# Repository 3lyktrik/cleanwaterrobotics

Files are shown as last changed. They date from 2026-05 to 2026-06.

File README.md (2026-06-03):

# Clean Water Robotics
Είμαστε η ομάδα **"Clean Water Robotics"** από το **3ο ΓΕΛ Τρικάλων "Οδυσσέας Ελύτης"** και στα πλαίσια της συμμετοχής μας στον **"8ο Πανελλήνιο Διαγωνισμό Ανοιχτών Τεχνολογιών στην Εκπαίδευση"** υλοποιήσαμε το έργο **"Αυτόνομο Ρομπότ Συλλογής Μικροπλαστικών από Υδάτινα Οικοσυστήματα"**.

## Το πρόβλημα
Ένα πολύ μεγάλο πρόβλημα της σύγχρονης εποχής είναι το πρόβλημα των μικροπλαστικών.
Τα μικροπλαστικά είναι μικροσκοπικά σωματίδια πλαστικού με μέγεθος μικρότερο από 5 χιλιοστά.

Λόγω του μεγέθους τους, είναι συχνά αόρατα με γυμνό μάτι, αλλά βρίσκονται πλέον παντού: στους ωκεανούς, στο έδαφος, στον αέρα, ακόμα και στον ανθρώπινο οργανισμό.

Επίσης ανιχνεύονται στα ποτάμια και στις λίμνες, καθώς και σε όλες τις υδάτινες διαδρομές από την ξηρά έως τη θάλασσα.

Τα μικροπλαστικά αποτελούν τεράστιο πρόβλημα τόσο για το περιβάλλον, όσο και για όλους τους ζωντανούς οργανισμούς, καθώς δεν βιοδιασπώνται εύκολα, παραμένουν στο περιβάλλον για αιώνες, εισέρχονται στην τροφική αλυσίδα των ζώων και του ανθρώπου, περιέχουν τοξικά πρόσθετα που μπορεί να προκαλέσουν πολλά προβλήματα υγείας, κλπ

Για την αντιμετώπιση του προβλήματος των μικροπλαστικών έχουν προταθεί διάφορες λύσεις.

Δείτε αναλυτικά την **έρευνα** που κάναμε για αυτό το πρόβλημα στο [docs/Έρευνα.md](docs/Έρευνα.md).

## Η λύση: “Αυτόνομο Ρομπότ Συλλογής Μικροπλαστικών από Υδάτινα Οικοσυστήματα”
Η ομάδα μας σχεδίασε και κατασκεύασε ένα αυτόνομο ρομποτικό σκάφος, με στόχο τη μείωση της ρύπανσης από πλαστικά στα υδάτινα οικοσυστήματα, μέσω ελεγχόμενου φιλτραρίσματος του νερού.
Το έργο μας επικεντρώνεται στην πρόληψη της μεταφοράς πλαστικών σωματιδίων από τα εσωτερικά ύδατα (ποτάμια, λίμνες) προς τη θάλασσα, συμβάλλοντας στην προστασία όλων  των υδάτινων οικοσυστημάτων.

Πρόκειται για ένα σκάφος τύπου καταμαράν, που κατασκευάσαμε από σωλήνες PVC διαμέτρου Φ100.

Το σκάφος ελέγχεται από ένα μικροελεγκτή arduino και κινείται με τη βοήθεια δύο ανεξάρτητων κινητήρων, οι οποίοι δίνουν κίνηση σε δύο προπέλες.

Η ενέργεια παρέχεται από μια επαναφορτιζόμενη μπαταρία και πάνω στο σκάφος υπάρχει ηλιακό πάνελ για τη φόρτισή της.

Ο καθαρισμός του νερού από τα μικροπλαστικά γίνεται με φιλτράρισμα, με βυθιζόμενη αντλία σε ελεγχομένο βάθος.

Η πλοήγηση του σκάφους γίνεται με 3 τρόπους:
- με τηλεχειρισμό, μέσω μιας εφαρμογής για κινητά android που αναπτύξαμε
- με κάμερα τεχνητής νοημοσύνης που εντοπίζει μια  πινακίδα στην όχθη και καθοδηγεί ανάλογα το σκάφος
- με χειρονομίες, μέσω κατάλληλης κάμερας αναγνώρισης χειρονομιών

Επίσης γίνεται παρακολούθηση του σκάφους με GPS.

Δείτε αναλυτικά όλες τις λεπτομέρειες της λύσης μας, το σχεδιασμό, την υλοποίηση, τα υλικά και το κόστος εδώ: [docs/Σχεδιασμός.md](docs/Σχεδιασμός.md)

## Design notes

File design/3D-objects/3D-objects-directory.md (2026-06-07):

Στο φάκελο 3D-objects βρίσκονται τα αρχεία stl από το TinkerCAD.
Πρόκειται για τις προπέλες, την τροχαλία και τις βάσεις του servo, των κινητήρων, των πλωτήρων και του φίλτρου.
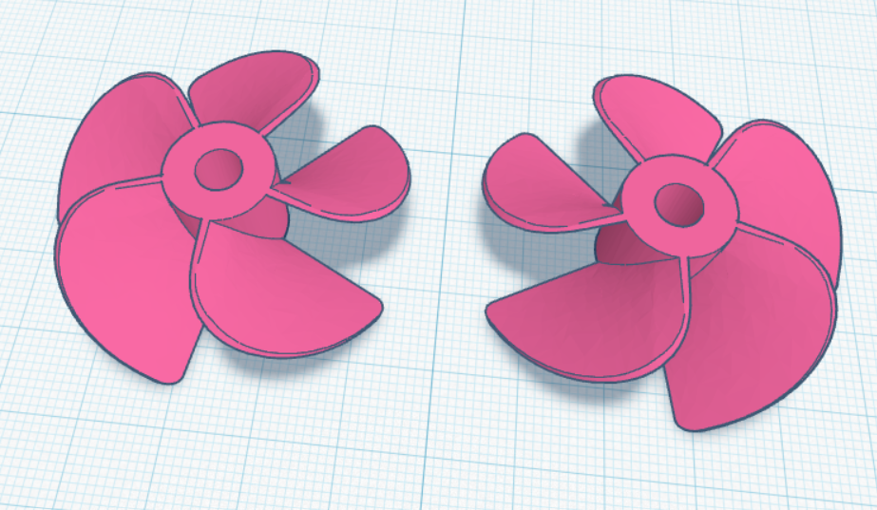
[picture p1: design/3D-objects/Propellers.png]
Προπέλες

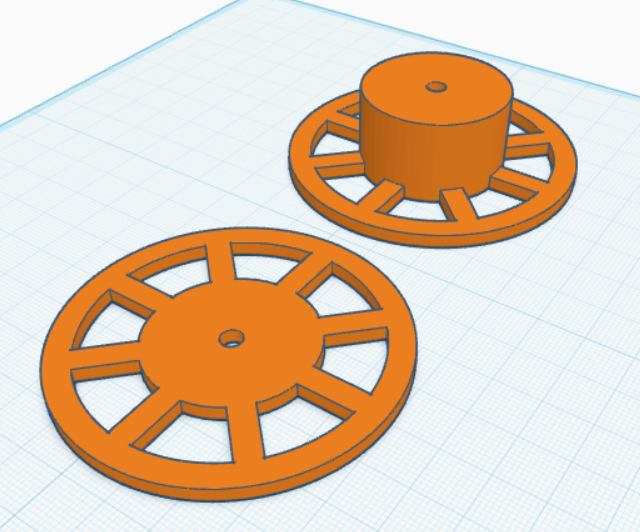
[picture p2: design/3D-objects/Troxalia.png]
Τροχαλία

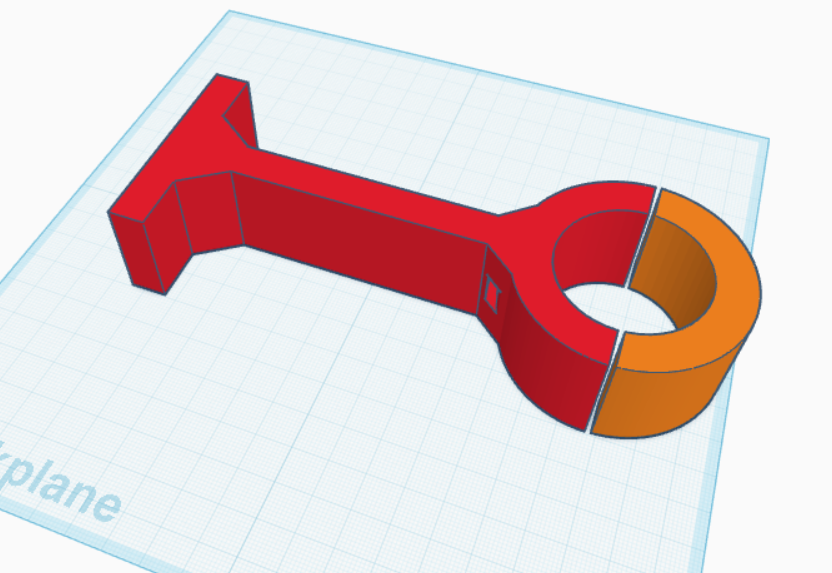
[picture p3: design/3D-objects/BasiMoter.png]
Βάση μοτέρ

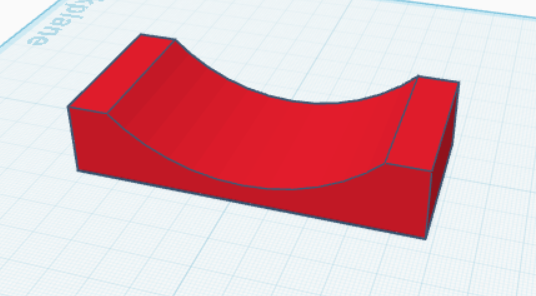
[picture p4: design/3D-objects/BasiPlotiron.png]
Βάση πλωτήρων

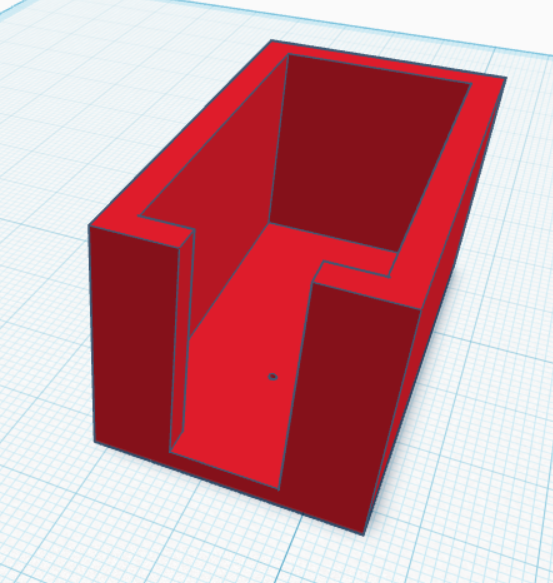
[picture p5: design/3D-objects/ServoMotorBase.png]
Βάση σέρβο

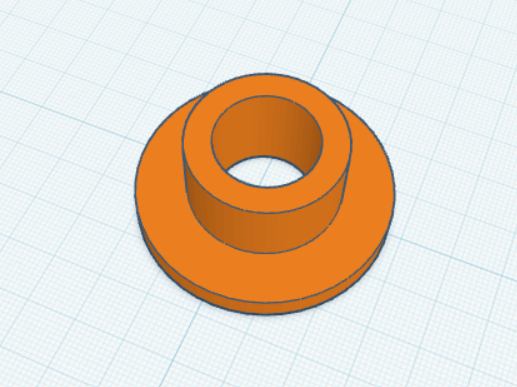
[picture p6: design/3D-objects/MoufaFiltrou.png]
Βάση φίλτρου


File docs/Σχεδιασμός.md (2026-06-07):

# Σχεδιασμός

## Σαφής ορισμός προτεινόμενης λύσης

### Η λύση μας: "Αυτόνομο Ρομπότ Συλλογής Μικροπλαστικών από Υδάτινα Οικοσυστήματα"

Η ομάδα μας σχεδίασε και κατασκεύασε ένα αυτόνομο ρομποτικό σκάφος, με στόχο τη μείωση της ρύπανσης από πλαστικά στα υδάτινα οικοσυστήματα, μέσω ελεγχόμενου φιλτραρίσματος του νερού.

Το έργο μας επικεντρώνεται στην πρόληψη της μεταφοράς πλαστικών σωματιδίων από τα εσωτερικά ύδατα (ποτάμια, λίμνες) προς τη θάλασσα, συμβάλλοντας στην προστασία όλων των υδάτινων οικοσυστημάτων.

Πρόκειται για ένα σκάφος τύπου καταμαράν, που κατασκευάσαμε από σωλήνες PVC διαμέτρου Φ100, για υψηλή πλευστότητα και σταθερότητα. Το σκάφος ελέγχεται από ένα μικροελεγκτή arduino και κινείται με τη βοήθεια δύο ανεξάρτητων κινητήρων, οι οποίοι δίνουν κίνηση σε δύο προπέλες.

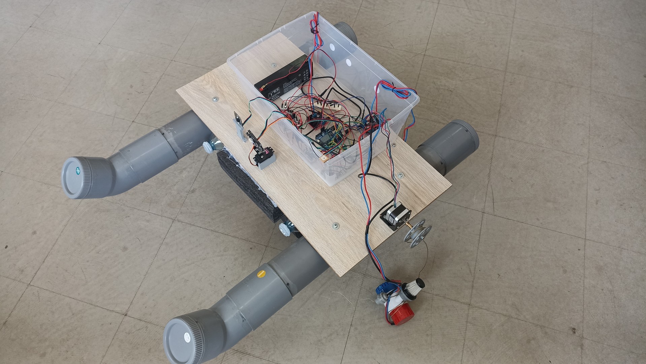
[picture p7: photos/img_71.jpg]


#### Πλοήγηση του σκάφους

Η πλοήγηση του σκάφους γίνεται μέσω της εφαρμογής για κινητά android που αναπτύξαμε με το App Inventor. Η εφαρμογή επικοινωνεί με το σκάφος με Bluetooth Low Energy (BLE). Υλοποιήσαμε 3 τρόπους πλοήγησης:

- **Πλοήγηση με Τηλεχειρισμό**

Στην εφαρμογή υπάρχουν δύο ρυθμιστικά (μπάρες ολίσθησης ή sliders), ένα για την αριστερή προπέλα και ένα για τη δεξιά, που ρυθμίζουν την ταχύτητα των αντίστοιχων κινητήρων. Έχουμε υλοποιήσει 4 ταχύτητες μπροστά και 4 όπισθεν. Οι στροφές του σκάφους επιτυγχάνονται με συνδυασμό ταχυτήτων των δύο κινητήρων (ο ένας μπροστά και ο άλλος όπισθεν).

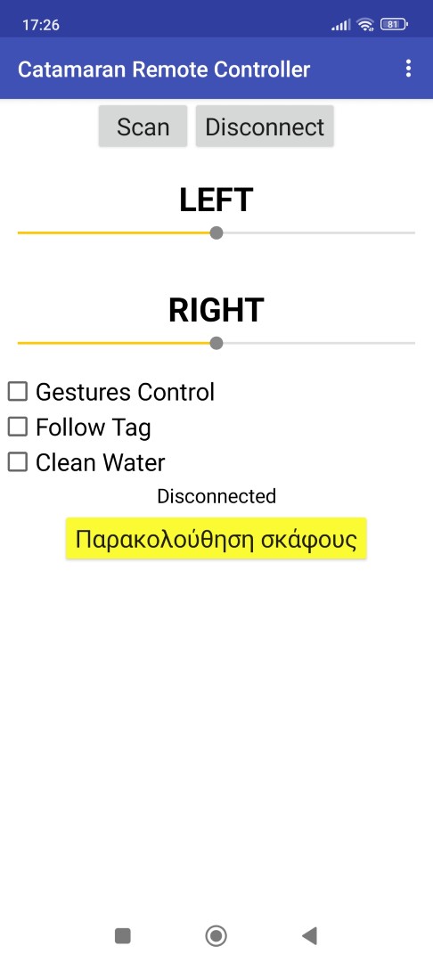
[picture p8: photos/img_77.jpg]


- **Πλοήγηση με χειρονομίες**

Στο σκάφος τοποθετήσαμε μια κάμερα αναγνώρισης χειρονομιών, την οποία χρησιμοποιούμε για να οδηγήσουμε το σκάφος από την όχθη με χειρονομίες. Υλοποιήσαμε τρεις χειρονομίες:

"ΟΚ" (👍) για κίνηση μπροστά, "STOP" (🤚) για σταμάτημα και "τηλέφωνο"(🤙) για κίνηση προς τα πίσω.

- **Πλοήγηση με κάμερα παρακολούθησης πινακίδας**

Το σκάφος είναι εξοπλισμένο και με μια ακόμα κάμερα τεχνητής νοημοσύνης, που χρησιμοποιούμε για αναγνώριση πινακίδων. Έχουμε εκτυπώσει σε μεγάλο μέγεθος μια πινακίδα με μία συγκεκριμένη εικόνα, η οποία είναι μία από τα λεγόμενα April Tags, που είναι εύκολο να αναγνωριστούν από την κάμερα.

Η κάμερα είναι στερεωμένη πάνω σε έναν κινητήρα servo για να μπορεί να περιστρέφεται. Με την κατάλληλη εντολή από την εφαρμογή του χειριστηρίου ("Follow Tag"), η κάμερα σαρώνει το χώρο για να εντοπίσει την πινακίδα. Αν δεν τη βρει στο οπτικό της πεδίο, τότε δίνει εντολή στο σκάφος να περιστραφεί λίγο, για να σαρώσει τελικά όλο τον κύκλο (360 μοίρες). Μόλις εντοπίσει την πινακίδα, στρίβει το σκάφος κατάλληλα ώστε να την κεντράρει και να αρχίσει να κατευθύνεται προς αυτήν.

Η πινακίδα τοποθετείται στην όχθη για να υποδεικνύει το σημείο επιστροφής του σκάφους, δηλαδή τη "βάση" του.

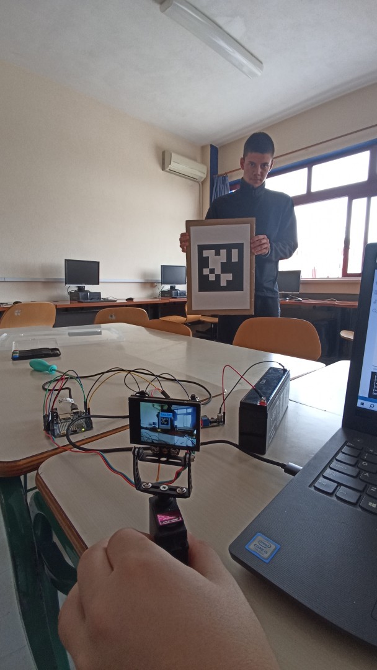
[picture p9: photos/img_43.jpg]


#### Παρακολούθηση του σκάφους με GPS

Για να αποφύγουμε το ενδεχόμενο να παρασυρθεί το σκάφος από τη ροή του ποταμού, χρησιμοποιούμε ένα δέκτη GPS, που καταγράφει τα δεδομένα θέσης του σκάφους (δηλ. συντεταγμένες, κατεύθυνση, ταχύτητα και αριθμός ορατών δορυφόρων) και τα στέλνει στην πλατφόρμα Thingspeak στο διαδίκτυο. Η εφαρμογή του κινητού ανακτά τα δεδομένα αυτά από την πλατφόρμα και απεικονίζει τη θέση του σκάφους πάνω στο χάρτη.

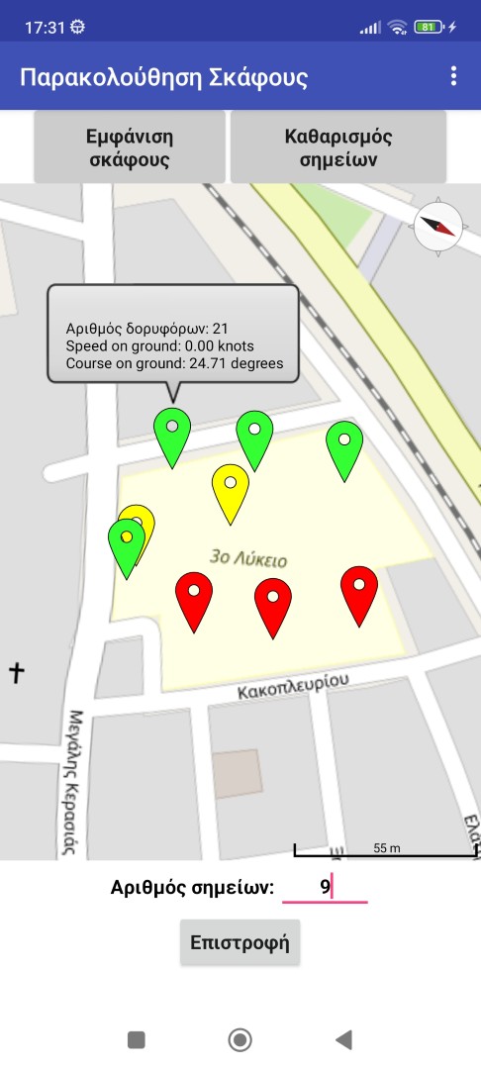
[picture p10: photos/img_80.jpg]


#### Καθαρισμός του νερού

Ο καθαρισμός του νερού από τα πλαστικά και μικροπλαστικά γίνεται με φιλτράρισμα. Το σύστημα καθαρισμού αποτελείται από:

- υποβρύχια αντλία άντλησης νερού
- φίλτρο ειδικά προσαρμοσμένο στην αντλία
- περιστρεφόμενο μηχανισμό καθόδου/ανόδου της αντλίας
- βηματικό κινητήρα για ακριβή έλεγχο της θέσης της αντλίας
- υποβρύχιο αισθητήρα απόστασης για μέτρηση του βάθους

Το φίλτρο είναι προσαρμοσμένο πάνω στην υποβρύχια αντλία. Η υποβρύχια αντλία μπορεί να βυθίζεται μέσα στο νερό, καθώς είναι στερεωμένη σε περιστρεφόμενο τροχό (τροχαλία). Ο τροχός περιστρέφεται με τη βοήθεια ενός βηματικού κινητήρα (stepper motor). Το βάθος που φτάνει η αντλία ελέγχεται με έναν υποβρύχιο αισθητήρα απόστασης. Η εντολή εκκίνησης και τερματισμού του καθαρισμού δίνεται από το χειριστήριο.

Με αυτόν τον τρόπο, το σκάφος μπορεί να πραγματοποιεί στοχευμένο φιλτράρισμα σε διαφορετικά βάθη νερού.

Η ικανότητα καθαρισμού της συγκεκριμένης αντλίας που χρησιμοποιήσαμε φτάνει τα 22 λίτρα/λεπτό και το μέγιστο βάθος λειτουργίας είναι 3.8 μέτρα.

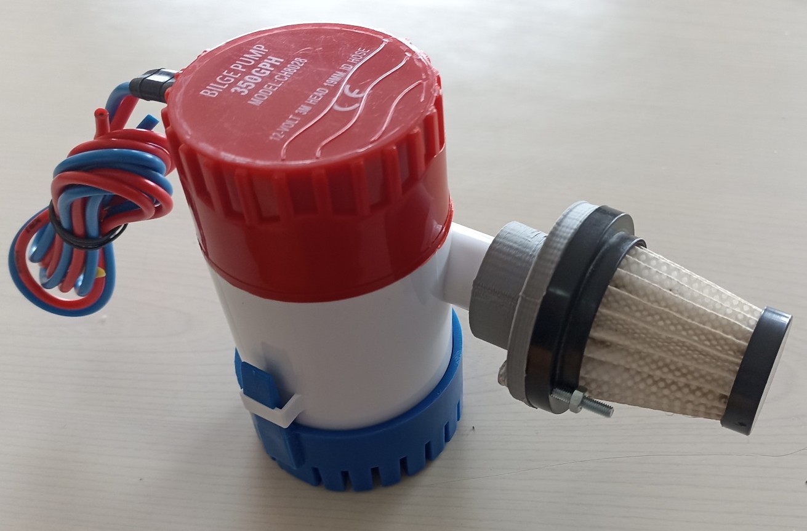
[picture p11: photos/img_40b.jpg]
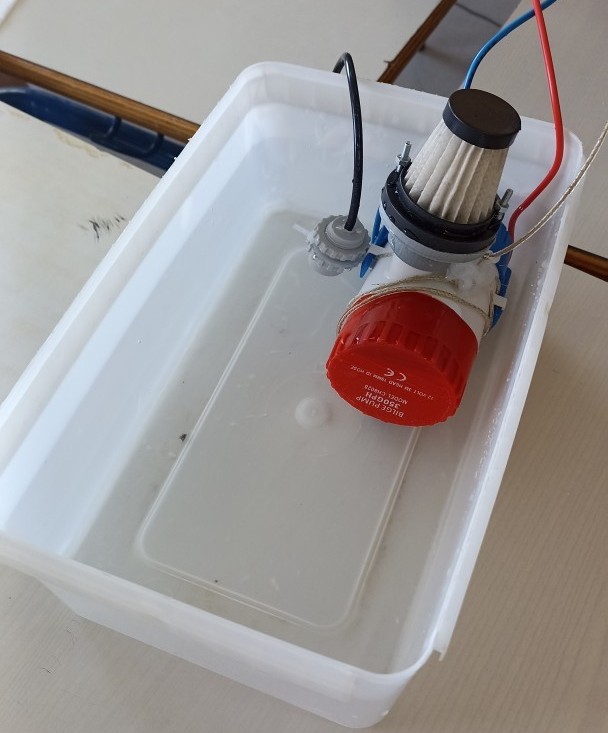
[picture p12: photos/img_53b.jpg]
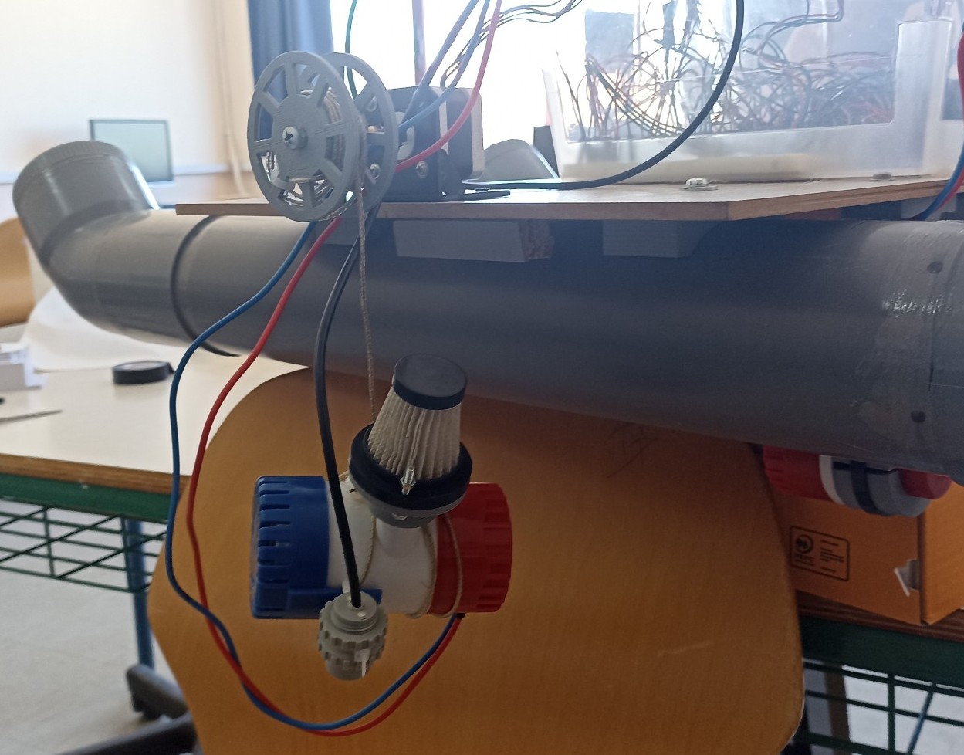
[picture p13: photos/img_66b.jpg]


#### Εκτυπώσεις 3D

Η ομάδα σχεδίασε στο TinkerCAD και εκτύπωσε στον τρισδιάστατο εκτυπωτή του σχολείου τα ακόλουθα αντικείμενα:

- Προπέλες (δεξιόστροφη - αριστερόστροφη)
- Τροχαλία για τη βύθιση της αντλίας καθαρισμού
- Βάσεις στήριξης των κινητήρων του σκάφους
- Βάσεις στήριξης των πλωτήρων (σωλήνων PVC) στο κατάστρωμα
- Βάση μοτέρ servo για την περιστροφή της κάμερας
- Βάση της κάμερας χειρονομιών
- Μούφα για σύνδεση του φίλτρου στην αντλία

Δείτε τα σχέδια παρακάτω.

#### Αυτονομία σκάφους

Το σκάφος λειτουργεί με μία επαναφορτιζόμενη μπαταρία 12V. Για τη φόρτισή της με ενεργειακά αποδοτικό τρόπο, αξιοποιούμε ανανεώσιμες πηγές ενέργειας, καθώς έχουμε εγκαταστήσει στο σκάφος ένα φωτοβολταϊκό πάνελ και μία πλακέτα φόρτισης.

Αρχικά χρησιμοποιήσαμε μικρή μπαταρία 2.3Ah, η οποία αποδείχθηκε ανεπαρκής για τις ανάγκες τροφοδοσίας όλων των κινητήρων ταυτόχρονα, οπότε η χρήση μιας μπαταρίας 9Ah κρίνεται αναγκαία.

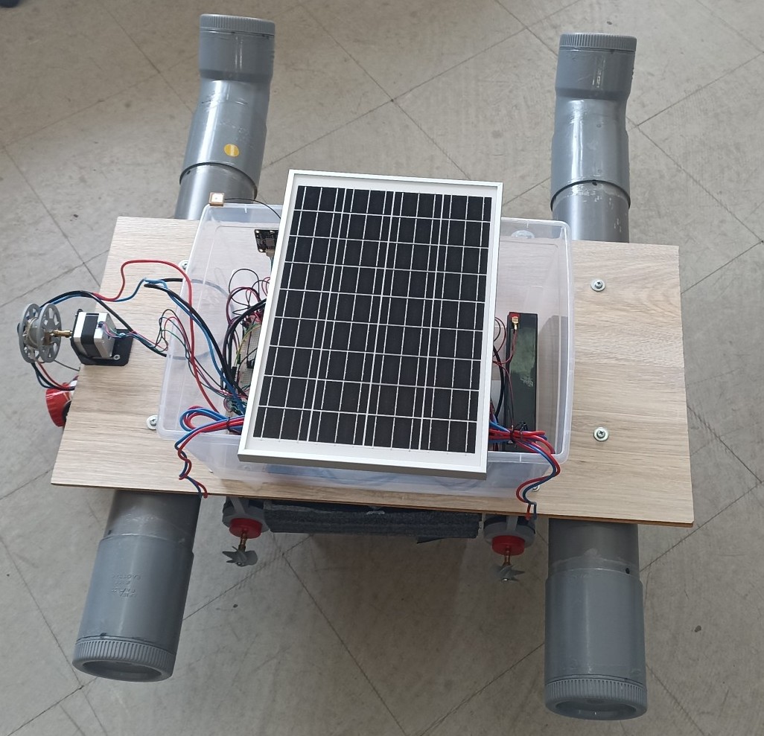
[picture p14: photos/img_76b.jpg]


## Πρωτοτυπία λύσης - καινοτομία

Η καινοτομία του έργου βρίσκεται:

- στον συνδυασμό πλωτού σκάφους και φιλτραρίσματος
- στον δυναμικό έλεγχο του βάθους καθαρισμού
- στην ποικιλία τρόπων πλοήγησης
- στη δυνατότητα αυτόνομης λειτουργίας
- στη χρήση ανοιχτών τεχνολογιών χαμηλού κόστους
- στη δυνατότητα εύκολης ανακατασκευής του έργου

## Λίστα υλικών και εργαλείων - Κόστος

|**Α/Α**|  **Είδος** |  **Περιγραφή** | **Τιμή** | **Τεμάχια** |  **Σύνολο**|
|----|---|---|---|---|---|
| 1 | Arduino | Arduino UNO R4 WiFi | 32,80 | 1 | 32,80 |
| 2 | Κουτί αδιάβροχο | Sonoff IP66 Waterproof Case | 4,90 | 1 | 4,90 |
| 3 | Πλακέτα δοκιμών | Πλακέτα Δοκιμών 400 Οπές - Άσπρη | 2,20 | 1 | 2,20 |
| 4 | Καλώδια | Jumper Wires 15cm Male to Male - Pack of 10 | 1,80 | 3 | 5,40 |
| 5 | Καλώδια | Jumper Wires 15cm Female to Male - Pack of 10 | 1,80 | 2 | 3,60 |
| 6 | Οδηγός κινητήρων DC | Dual Motor Driver Module L298N | 4,20 | 2 | 8,40 |
| 7 | Οδηγός κινητήρων stepper | DRV8825 Stepper Motor Driver | 3,20 | 1 | 3,20 |
| 8 | Βηματικός κινητήρας | Βηματικός Κινητήρας 2.8kg.cm (200 steps/rev) 42BYGHW208 | 12,60 | 1 | 12,60 |
| 9 | Αντλία και κινητήρες | Bilge Water Pump 12V 350GPH | 16,80 | 3 | 50,40 |
| 10 | Κινητήρας Servo | Waveshare MG996R Standard Servo with Metal Gears - 11kg·cm | 8,90 | 1 | 8,90 |
| 11 | Υποβρύχιος αισθητήρας απόστασης | Underwater Ultrasonic Distance Sensor IP68 - UART, 3m Range | 39,90 | 1 | 39,90 |
| 12 | Κάμερα AI | Gravity HUSKYLENS - An Easy-to-use AI Machine Vision Sensor | 69,90 | 1 | 69,90 |
| 13 | Κάμερα AI για χειρονομίες | DFRobot Gravity Gesture & Face Detection AI Sensor | 19,90 | 1 | 19,90 |
| 14 | Δέκτης GPS | Gravity GNSS GPS BeiDou Receiver Module - I2C&UART | 22,80 | 1 | 22,80 |
| 15 | Μπαταρία | Μπαταρία Μολύβδου 12V 2.3Ah | 9,60 | 1 | 9,60 |
| 16 | Φορτιστής για φωτοβολταϊκό | DFRobot Solar Power Manager for 12V Lead-Acid Battery | 35,90 | 1 | 35,90 |
| 17 | Φωτοβολταϊκό | Waveshare Φωτοβολταϊκή Κυψέλη 10W 340x232mm | 14,80 | 1 | 14,80 |
| 23 | Νήμα 3D εκτύπωσης | Creality Ender-PLA - 1.75mm 1kg Black | 14 | 1 | 14,00 |
| 24 | Σταθεροποιητής τάσης 5V | Voltage Regulator L7805CV - 5V 1.5A | 0,40 | 1 | 0,40 |
| 25 | Ψύκτρα | Ψύκτρα ΤO-220 20x15x10mm | 0,30 | 1 | 0,30 |
| 26 | Καλώδιο USB | Καλώδιο USB A Αρσενικό σε C Αρσενικό - 1m Μαύρο 3A | 2,30 | 1 | 2,30 |
| 27 | Σύνδεσμοι αξόνων | Shaft Coupler Solid 3.175mm - 5mm | 1,80 | 3 | 5,40 |
| 28 | Μετατροπέας τάσης | Lm2596s Dc-dc Step-down Power Supply | 2,47 | 1 | 2,47 |
| 29 | Σωλήνες PVC Φ100, γωνίες, μούφες, τάπες | | 40,00 | 1 | 40,00 |
| | | | | | |
| | | | **ΣΥΝΟΛΟ:** | | 410,07 |

## Σχέδια

Το αναλυτικό κύκλωμα φαίνεται στην παρακάτω εικόνα:
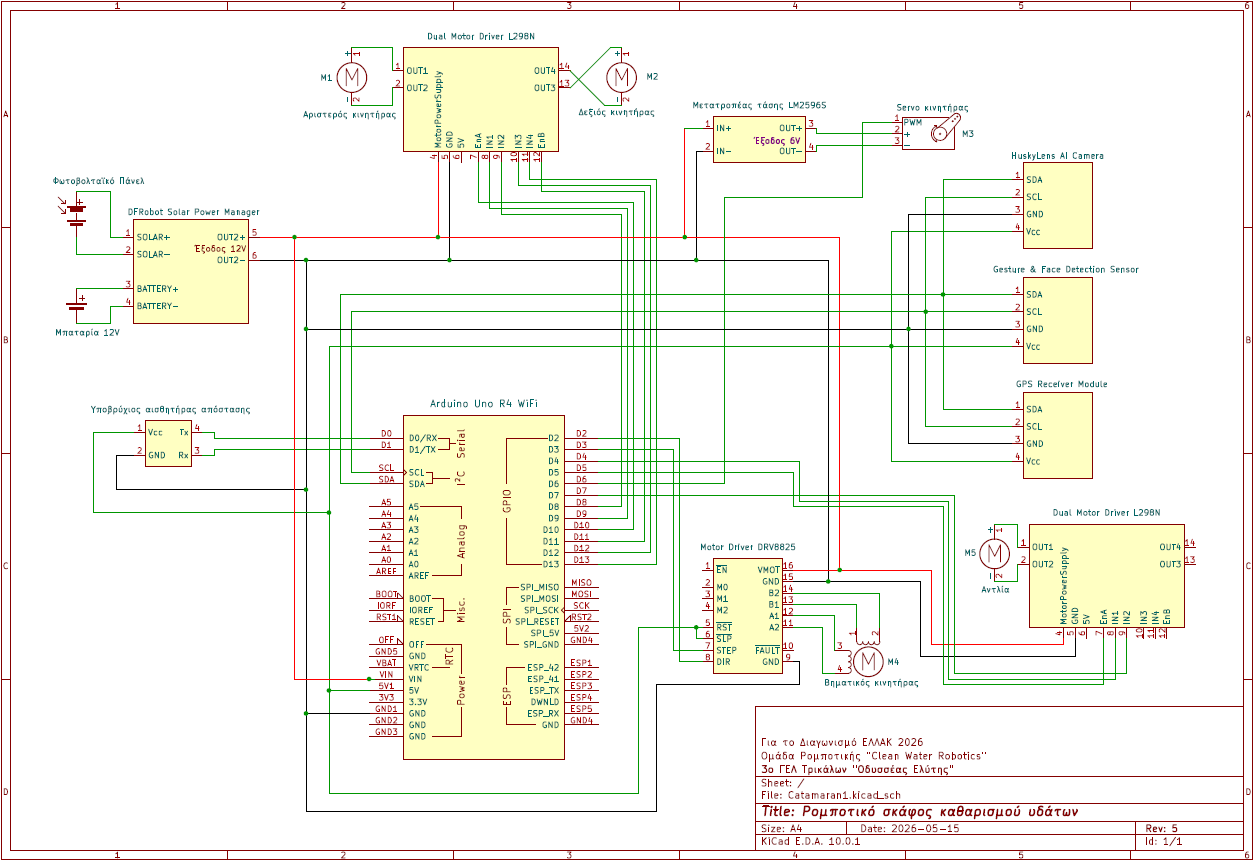
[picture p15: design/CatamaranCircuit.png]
Κύκλωμα


### Προπέλες
Προπέλες

### Τροχαλία
Τροχαλία

### Βάση servo
Βάση servo

### Βάση κινητήρων
Βάση μοτέρ

### Βάση πλωτήρων
Βάση πλωτήρων

### Βάση φίλτρου
Βάση φίλτρου

Βρείτε όλα τα αρχεία stl [εδώ](/design/3D-objects).

## Βασικός αλγόριθμος Arduino - App Inventor
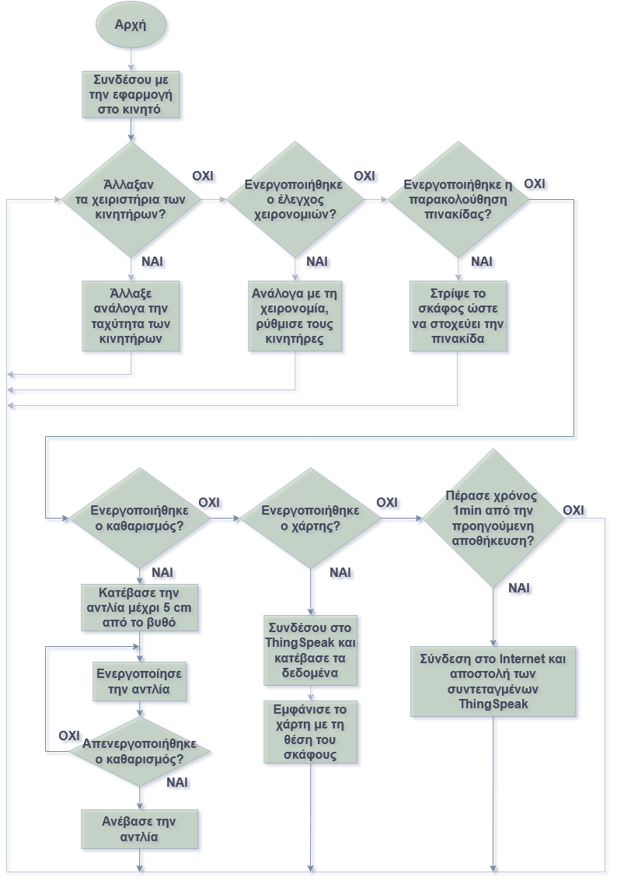
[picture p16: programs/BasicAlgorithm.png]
Βασικός Αλγόριθμος


## Αφίσα
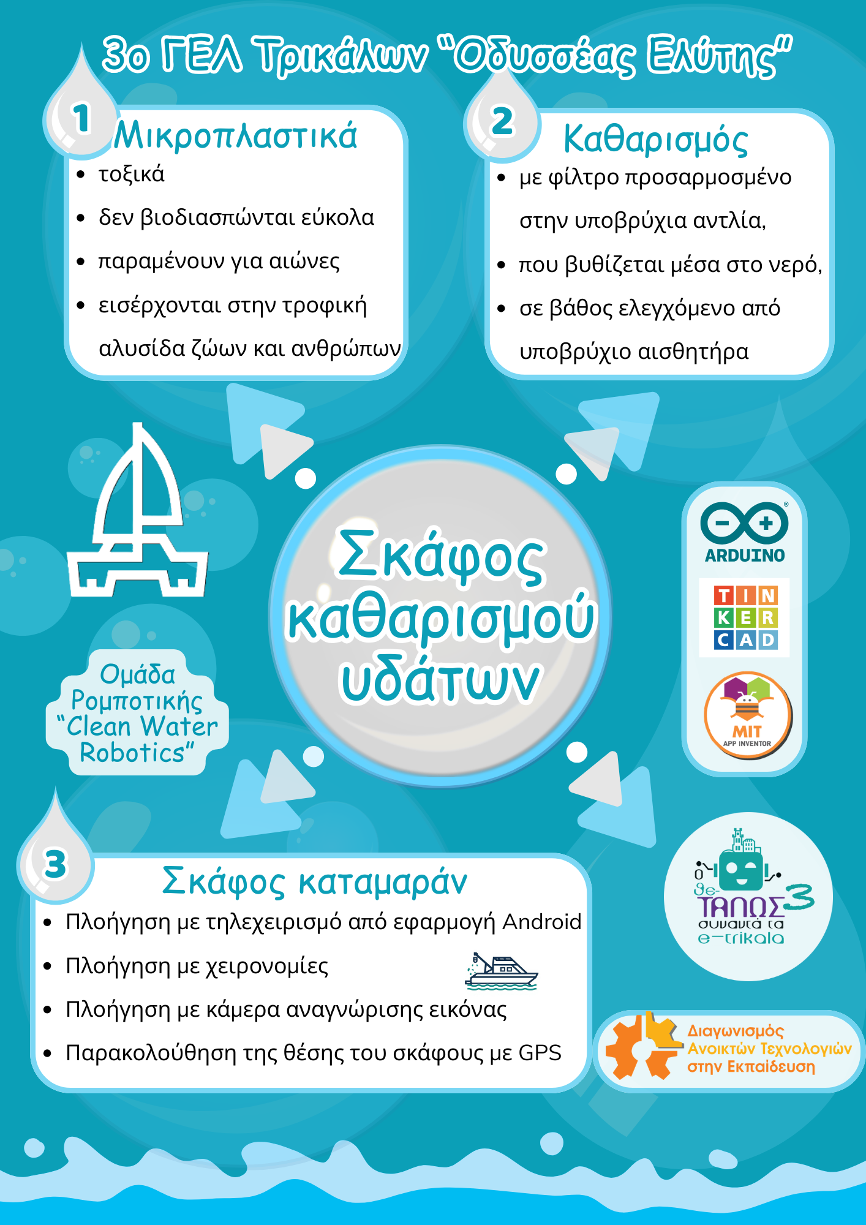
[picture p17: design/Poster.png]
Αφίσα


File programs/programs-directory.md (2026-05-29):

Εδώ βρίσκονται τα προγράμματα για το Arduino.

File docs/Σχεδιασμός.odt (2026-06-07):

# Σχεδιασμός

## Σαφής ορισμός προτεινόμενης λύσης

### Η λύση μας: “Αυτόνομο Ρομπότ Συλλογής Μικροπλαστικών από Υδάτινα Οικοσυστήματα”

Η ομάδα μας σχεδίασε και κατασκεύασε ένα αυτόνομο ρομποτικό σκάφος, με στόχο τη μείωση της ρύπανσης από πλαστικά στα υδάτινα οικοσυστήματα, μέσω ελεγχόμενου φιλτραρίσματος του νερού.

Το έργο μας επικεντρώνεται στην πρόληψη της μεταφοράς πλαστικών σωματιδίων από τα εσωτερικά ύδατα (ποτάμια, λίμνες) προς τη θάλασσα, συμβάλλοντας στην προστασία όλων των υδάτινων οικοσυστημάτων.

Πρόκειται για ένα σκάφος τύπου καταμαράν, που κατασκευάσαμε από σωλήνες PVC διαμέτρου Φ100, για υψηλή πλευστότητα και σταθερότητα. Το σκάφος ελέγχεται από ένα μικροελεγκτή arduino και κινείται με τη βοήθεια δύο ανεξάρτητων κινητήρων, οι οποίοι δίνουν κίνηση σε δύο προπέλες.

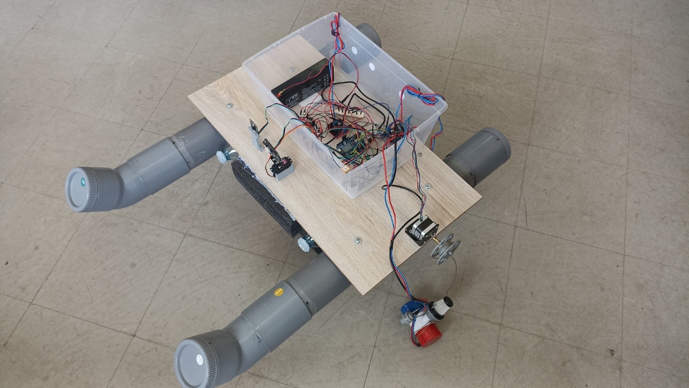
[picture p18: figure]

#### Πλοήγηση του σκάφους

Η πλοήγηση του σκάφους γίνεται μέσω της εφαρμογής για κινητά android που αναπτύξαμε με το App Inventor. Η εφαρμογή επικοινωνεί με το σκάφος με Bluetooth Low Energy (BLE). Υλοποιήσαμε 3 τρόπους πλοήγησης:

1. Πλοήγηση με Τηλεχειρισμό

Στην εφαρμογή υπάρχουν δύο ρυθμιστικά (μπάρες ολίσθησης ή sliders), ένα για την αριστερή προπέλα και ένα για τη δεξιά, που ρυθμίζουν την ταχύτητα των αντίστοιχων κινητήρων. Έχουμε υλοποιήσει 4 ταχύτητες μπροστά και 4 όπισθεν. Οι στροφές του σκάφους επιτυγχάνονται με συνδυασμό ταχυτήτων των δύο κινητήρων (ο ένας μπροστά και ο άλλος όπισθεν).

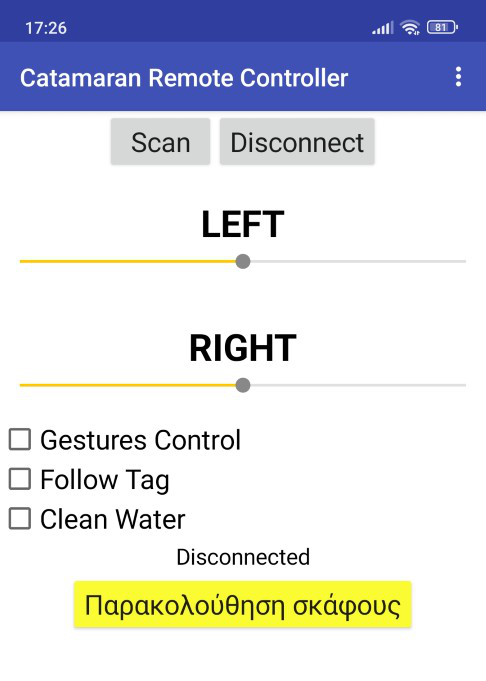
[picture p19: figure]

2. Πλοήγηση με χειρονομίες

Στο σκάφος τοποθετήσαμε μια κάμερα αναγνώρισης χειρονομιών, την οποία χρησιμοποιούμε για να οδηγήσουμε το σκάφος από την όχθη με χειρονομίες. Υλοποιήσαμε τρεις χειρονομίες:

“ΟΚ” (👍) για κίνηση μπροστά, “STOP” (🤚) για σταμάτημα και “τηλέφωνο”(🤙) για κίνηση προς τα πίσω.

3. Πλοήγηση με κάμερα παρακολούθησης πινακίδας

Το σκάφος είναι εξοπλισμένο και με μια ακόμα κάμερα τεχνητής νοημοσύνης, που χρησιμοποιούμε για αναγνώριση πινακίδων. Έχουμε εκτυπώσει σε μεγάλο μέγεθος μια πινακίδα με μία συγκεκριμένη εικόνα, η οποία είναι μία από τα λεγόμενα April Tags, που είναι εύκολο να αναγνωριστούν από την κάμερα.

Η κάμερα είναι στερεωμένη πάνω σε έναν κινητήρα servo για να μπορεί να περιστρέφεται. Με την κατάλληλη εντολή από την εφαρμογή του χειριστηρίου (“Follow Tag”), η κάμερα σαρώνει το χώρο για να εντοπίσει την πινακίδα. Αν δεν τη βρει στο οπτικό της πεδίο, τότε δίνει εντολή στο σκάφος να περιστραφεί λίγο, για να σαρώσει τελικά όλο τον κύκλο (360 μοίρες). Μόλις εντοπίσει την πινακίδα, στρίβει το σκάφος κατάλληλα ώστε να την κεντράρει και να αρχίσει να κατευθύνεται προς αυτήν.

Η πινακίδα χρησιμοποιείται για να υποδεικνύει το σημείο επιστροφής του σκάφους, δηλαδή τη “βάση” του.


#### Παρακολούθηση του σκάφους με GPS

Για να αποφύγουμε το ενδεχόμενο να παρασυρθεί το σκάφος από τη ροή του ποταμού, χρησιμοποιούμε ένα δέκτη GPS, που καταγράφει τα δεδομένα θέσης του σκάφους (δηλ. συντεταγμένες, κατεύθυνση, ταχύτητα και αριθμός ορατών δορυφόρων) και τα στέλνει στην πλατφόρμα Thingspeak στο διαδίκτυο. Η εφαρμογή του κινητού ανακτά τα δεδομένα αυτά από την πλατφόρμα και απεικονίζει τη θέση του σκάφους πάνω στο χάρτη.

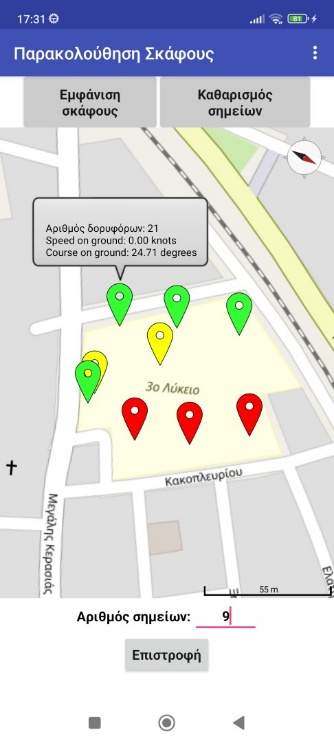
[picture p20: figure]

#### Καθαρισμός του νερού

Ο καθαρισμός του νερού από τα πλαστικά και μικροπλαστικά γίνεται με φιλτράρισμα. Το σύστημα καθαρισμού αποτελείται από:

- υποβρύχια αντλία άντλησης νερού
- φίλτρο ειδικά προσαρμοσμένο στην αντλία
- περιστρεφόμενο μηχανισμό καθόδου/ανόδου της αντλίας
- βηματικό κινητήρα για ακριβή έλεγχο της θέσης της αντλίας
- υποβρύχιο αισθητήρα απόστασης για μέτρηση του βάθους

Το φίλτρο είναι προσαρμοσμένο πάνω στην υποβρύχια αντλία. Η υποβρύχια αντλία μπορεί να βυθίζεται μέσα στο νερό, καθώς είναι στερεωμένη σε περιστρεφόμενο τροχό (τροχαλία). Ο τροχός περιστρέφεται με τη βοήθεια ενός βηματικού κινητήρα (stepper motor). Το βάθος που φτάνει η αντλία ελέγχεται με έναν υποβρύχιο αισθητήρα απόστασης. Η εντολή εκκίνησης και τερματισμού του καθαρισμού δίνεται από το χειριστήριο.

Με αυτόν τον τρόπο, το σκάφος μπορεί να πραγματοποιεί στοχευμένο φιλτράρισμα σε διαφορετικά βάθη νερού.

Η ικανότητα καθαρισμού της συγκεκριμένης αντλίας που χρησιμοποιήσαμε φτάνει τα 22 λίτρα/λεπτό και το μέγιστο βάθος λειτουργίας είναι 3.8 μέτρα.

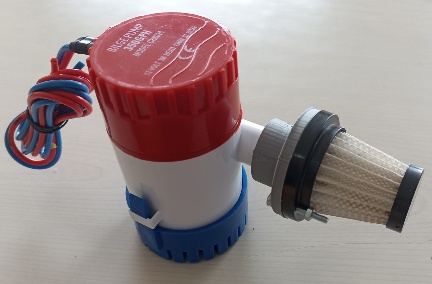
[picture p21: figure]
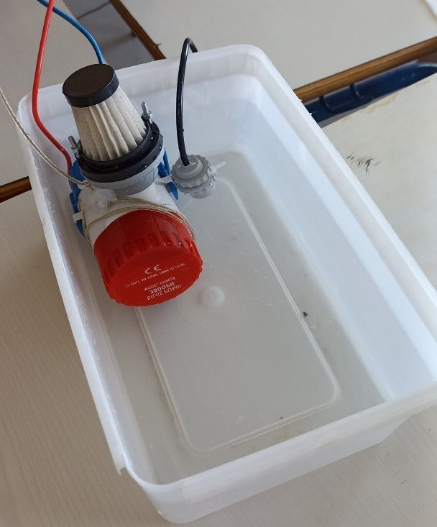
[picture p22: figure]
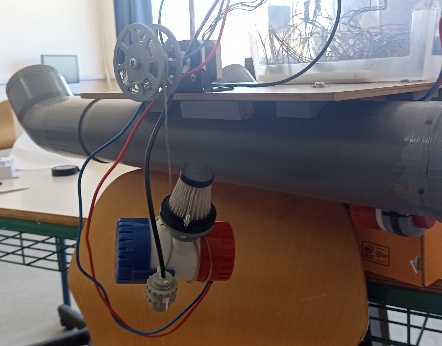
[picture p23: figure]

#### Εκτυπώσεις 3D

Η ομάδα σχεδίασε στο TinkerCAD και εκτύπωσε στον τρισδιάστατο εκτυπωτή του σχολείου τα ακόλουθα αντικείμενα:

- Προπέλες (δεξιόστροφη - αριστερόστροφη)
- Τροχαλία για τη βύθιση της αντλίας καθαρισμού
- Βάσεις στήριξης των κινητήρων του σκάφους
- Βάσεις στήριξης των πλωτήρων (σωλήνων PVC) στο κατάστρωμα
- Βάση μοτέρ servo για την περιστροφή της κάμερας
- Βάση της κάμερας χειρονομιών
- Μούφα για σύνδεση του φίλτρου στην αντλία

Δείτε τα σχέδια παρακάτω.

#### Αυτονομία σκάφους

Το σκάφος λειτουργεί με μία επαναφορτιζόμενη μπαταρία 12V. Για τη φόρτισή της με ενεργειακά αποδοτικό τρόπο, αξιοποιούμε ανανεώσιμες πηγές ενέργειας, καθώς έχουμε εγκαταστήσει στο σκάφος ένα φωτοβολταϊκό πάνελ και μία πλακέτα φόρτισης.

Αρχικά χρησιμοποιήσαμε μικρή μπαταρία 2.3Ah, η οποία αποδείχθηκε ανεπαρκής για τις ανάγκες τροφοδοσίας όλων των κινητήρων ταυτόχρονα, οπότε η χρήση μιας μπαταρίας 9Ah κρίνεται αναγκαία.


## Πρωτοτυπία λύσης - καινοτομία

Η καινοτομία του έργου βρίσκεται:

- στον συνδυασμό πλωτού σκάφους και φιλτραρίσματος
- στον δυναμικό έλεγχο του βάθους καθαρισμού
- στην ποικιλία τρόπων πλοήγησης
- στη δυνατότητα αυτόνομης λειτουργίας
- στη χρήση ανοιχτών τεχνολογιών χαμηλού κόστους
- στη δυνατότητα εύκολης ανακατασκευής του έργου

## Λίστα υλικών και εργαλείων - Κόστος

ΛΙΣΤΑ ΥΛΙΚΩΝ
Α/Α | Είδος | Περιγραφή | Τιμή μονάδας | Τεμάχια | Σύνολο
1 | Arduino | Arduino UNO R4 WiFi | 32,80 | 1 | 32,80
2 | Κουτί αδιάβροχο | Sonoff IP66 Waterproof Case | 4,90 | 1 | 4,90
3 | Πλακέτα δοκιμών | Πλακέτα Δοκιμών 400 Οπές - Άσπρη | 2,20 | 1 | 2,20
4 | Καλώδια | Jumper Wires 15cm Male to Male - Pack of 10 | 1,80 | 3 | 5,40
5 | Καλώδια | Jumper Wires 15cm Female to Male - Pack of 10 | 1,80 | 2 | 3,60
6 | Οδηγός κινητήρων DC | Dual Motor Driver Module L298N | 4,20 | 2 | 8,40
7 | Οδηγός κινητήρων stepper | DRV8825 Stepper Motor Driver | 3,20 | 1 | 3,20
8 | Βηματικός κινητήρας | Βηματικός Κινητήρας 2.8kg.cm (200 steps/rev) 42BYGHW208 | 12,60 | 1 | 12,60
9 | Αντλία και κινητήρες | Bilge Water Pump 12V 350GPH | 16,80 | 3 | 50,40
10 | Κινητήρας Servo | Waveshare MG996R Standard Servo with Metal Gears – 11kg·cm | 8,90 | 1 | 8,90
11 | Υποβρύχιος αισθητήρας απόστασης | Underwater Ultrasonic Distance Sensor IP68 - UART, 3m Range | 39,90 | 1 | 39,90
12 | Κάμερα AI | Gravity HUSKYLENS - An Easy-to-use AI Machine Vision Sensor | 69,90 | 1 | 69,90
13 | Κάμερα AI για χειρονομίες | DFRobot Gravity Gesture & Face Detection AI Sensor | 19,90 | 1 | 19,90
14 | Δέκτης GPS | Gravity GNSS GPS BeiDou Receiver Module - I2C&UART | 22,80 | 1 | 22,80
15 | Μπαταρία | Μπαταρία Μολύβδου 12V 2.3Ah | 9,60 | 1 | 9,60
16 | Φορτιστής για φωτοβολταϊκό | DFRobot Solar Power Manager for 12V Lead-Acid Battery | 35,90 | 1 | 35,90
17 | Φωτοβολταϊκό | Waveshare Φωτοβολταϊκή Κυψέλη 10W 340x232mm | 14,80 | 1 | 14,80
23 | Νήμα 3D εκτύπωσης | Creality Ender-PLA – 1.75mm 1kg Black | 14 | 1 | 14,00
24 | Σταθεροποιητής τάσης 5V | Voltage Regulator L7805CV - 5V 1.5A | 0,40 | 1 | 0,40
25 | Ψύκτρα | Ψύκτρα ΤO-220 20x15x10mm | 0,30 | 1 | 0,30
26 | Καλώδιο USB | Καλώδιο USB A Αρσενικό σε C Αρσενικό - 1m Μαύρο 3A | 2,30 | 1 | 2,30
27 | Σύνδεσμοι αξόνων | Shaft Coupler Solid 3.175mm - 5mm | 1,80 | 3 | 5,40
28 | Μετατροπέας τάσης | Lm2596s Dc-dc Step-down Power Supply | 2,47 | 1 | 2,47
29 | Σωλήνες PVC Φ100, γωνίες, μούφες, τάπες | | 40,00 | 1 | 40,00
| | | ΣΥΝΟΛΟ: | | 410,07

## Σχέδια

Το αναλυτικό κύκλωμα φαίνεται στην παρακάτω εικόνα:

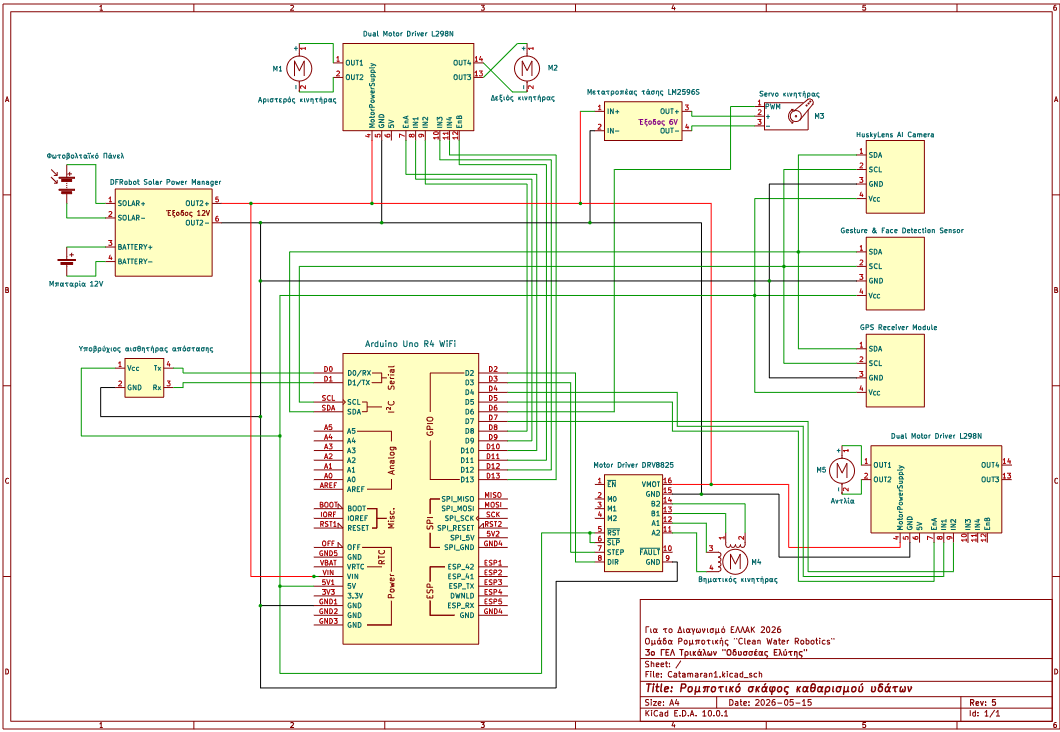
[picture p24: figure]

### Προπέλες


### Τροχαλία


### Βάσεις servo, κινητήρων, πλωτήρων, φίλτρου


## Βασικός αλγόριθμος Arduino - App Inventor


## Αφίσα


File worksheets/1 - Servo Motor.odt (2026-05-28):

Φύλλο Εργασίας 1

Κινητήρας Servo

## Δραστηριότητα 1

Μπείτε στο https://docs.arduino.cc/learn/electronics/servo-motors/ και κάντε τα παραδείγματα Knob και Sweep.

## Δραστηριότητα 2

Προγραμματίστε τον κινητήρα Servo έτσι ώστε να περιστρέφεται σε γωνία 90 μοιρών.

## Δραστηριότητα 3

Προγραμματίστε δύο συναρτήσεις με ονόματα turnServo1 και turnServo2, από τις οποίες η μία θα περιστρέφει το servo κατά περίπου 90 μοίρες, ενώ η άλλη θα το επαναφέρει στην αρχική του θέση.

### Ενδεικτική λύση:

void turnServo1(void)

{

for (int pos = 0; pos <= 120; pos++)

{

myservo.write(pos);

delay(10);

}

}

void turnServo2(void)

{

for (int pos = 120; pos >= 0; pos--)

{

myservo.write(pos);

delay(10);

}

}

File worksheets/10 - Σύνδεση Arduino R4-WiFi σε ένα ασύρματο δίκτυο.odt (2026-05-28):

# Φύλλο Εργασίας 10

# Σύνδεση του Arduino UNO R4 - WiFi σε ένα ασύρματο δίκτυο

Πηγές:

1. https://docs.arduino.cc/tutorials/uno-r4-wifi/wifi-examples/#connect-with-wpa
2. https://www.halvorsen.blog/documents/technology/iot/thingspeak/thingspeak.php

Από τον παραπάνω σύνδεσμο 1, βρείτε το παράδειγμα “Connect With WPA” (μπορείτε να το ανοίξετε και από τα παραδείγματα του Arduino IDE, στη θέση: Αρχείο -> Παραδείγματα -> WiFiS3 -> ConnectWithWPA).

Στο αρχείο (ή στην καρτέλα) arduino_secrets.h πληκτρολογήστε το SSID και το password του δικού σας δικτύου WiFi.

Εκτελέστε το παράδειγμα και επαληθεύστε ότι το Arduino συνδέεται στο δίκτυο WiFi.

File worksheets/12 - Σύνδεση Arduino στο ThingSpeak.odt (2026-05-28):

# Φύλλο Εργασίας 12

# Σύνδεση του Arduino UNO R4 - WiFi στο ThingSpeak

Πηγές:

1. https://www.halvorsen.blog/documents/technology/iot/thingspeak/thingspeak.php
2. https://github.com/mathworks/thingspeak-arduino
3. https://docs.arduino.cc/libraries/thingspeak

Στο Arduino μπορούμε να χρησιμοποιήσουμε τις υπηρεσίες του ThingSpeak μέσω της αντίστοιχης βιβλιοθήκης, που αναπτύσσεται από την κατασκευάστρια εταιρεία MathWorks.

Η τελευταία έκδοση της βιβλιοθήκης (ThingSpeak 2.1.1) είναι συμβατή με το hardware του Arduino UNO R4 - WiFi, όμως θα πρέπει να χρησιμοποιήσουμε ένα από τα παραδείγματα που λειτουργούν σε άλλο hardware, αφού πρώτα το τροποποιήσουμε ελαφρώς.

Έτσι, από τα παραδείγματα του Arduino IDE, στη θέση Αρχείο -> Παραδείγματα -> ThingSpeak -> ArduinoUnoWiFi Rev2 -> WriteMultipleFields ανοίγουμε τα δύο αρχεία του παραδείγματος Write Multiple Fields.

Στο αρχείο secrets.h πληκτρολογούμε το SSID και το password του δικτύου WiFi, καθώς επίσης το Channel ID και το Write API key του καναλιού μας στο ThingSpeak.

Στο αρχείο WriteMultripleFields.ino αλλάζουμε απλώς τη βιβλιοθήκη σε

#include <WiFiS3.h> // ΕΔΩ ΑΛΛΑΞΑΜΕ ΤΗ ΒΙΒΛΙΟΘΗΚΗ

Εκτελέστε το παράδειγμα και επαληθεύστε ότι το Arduino στέλνει στο κανάλι στο ThingSpeak τις 4 μεταβλητές κάθε 20 δευτερόλεπτα.

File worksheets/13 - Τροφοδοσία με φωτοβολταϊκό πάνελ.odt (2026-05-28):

# Φύλλο Εργασίας 13 Τροφοδοσία με μπαταρία επαναφορτιζόμενη από φωτοβολταϊκό πάνελ

## Υλικά

Πλακέτα | DFRobot Solar Power Manager for 12V Lead-Acid Battery
Φωτοβολταϊκό πάνελ | Waveshare Φωτοβολταϊκή Κυψέλη 10W 340x232mm
Μπαταρία | Μπαταρία Μολύβδου 12V 2.3Ah

## Δραστηριότητα

Μπείτε εδώ: https://wiki.dfrobot.com/dfr0580/ και κάντε την ενότητα “Getting Started”, όπου υπάρχουν αναλυτικές οδηγίες για τα παρακάτω βήματα:

1. Κολλήστε τις ψύκτρες στην πλακέτα στις θέσεις που φαίνονται στις εικόνες.
2. Συνδέστε την μπαταρία στην πλακέτα, στους ακροδέκτες BAT IN.
3. Συνδέστε το φωτοβολταϊκό στην πλακέτα, στους ακροδέκτες SOLAR IN.
4. Συνδέστε το Arduino στην πλακέτα, στη θύρα USB1.
5. Συνδέστε ένα breadboard (πλακέτα δοκιμών) στην πλακέτα, δίνοντας 5V από τους ακροδέκτες OUT1 στη μία πλευρά του breadboard (στις ράγες τροφοδοσίας), και 12V από τους ακροδέκτες OUT2 στην απέναντι πλευρά του breadboard.

Ελέγξτε τη σωστή λειτουργία του Arduino.


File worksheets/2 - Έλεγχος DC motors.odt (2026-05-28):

# Φύλλο Εργασίας 2

## Έλεγχος κινητήρων DC με την πλακέτα L298N H-Bridge

### Δραστηριότητα 1

Μελετήστε τη συνδεσμολογία της πλακέτας ελέγχου του κινητήρα.


Αριθμός | Συνδέσεις
1,2 | Εδώ συνδέουμε το μοτέρ συνεχούς ρεύματος (DC).
3 | Βραχυκυκλωτήρας που ενεργοποιεί τον ενσωματωμένο regulator 5V, ο οποίος θα δίνει 5V στο pin 6. Τον αφαιρούμε αν στην επόμενη σύνδεση 4 εφαρμόζουμε πάνω από 12V DC. Στην περίπτωση αυτή, πρέπει να τροφοδοτήσουμε την πλακέτα με 5V στο pin 6.
4 | Ο θετικός πόλος της μπαταρίας (τροφοδοσία μοτέρ).
5 | Γείωση (GND). Ο αρνητικός πόλος της μπαταρίας, που συνδέεται οπωσδήποτε και με τη γείωση του arduino.
6 | Είσοδος 5V για την πλακέτα ελέγχου, αφού έχουμε αφαιρέσει το βραχυκυκλωτήρα 3.
7 | ENA (Enable A): Αφαιρούμε το βραχυκυκλωτήρα και συνδέουμε την έξοδο (PWM οπωσδήποτε) του arduino που ελέγχει την ταχύτητα του μοτέρ.
8, 9 | IN1 και IN2: συνδέονται σε 2 ψηφιακές εξόδους του Arduino και καθορίζουν τη φορά περιστροφής του μοτέρ.
Τα pins 10-14 είναι για το 2ο μοτέρ.
10, 11 | IN3 και ΙΝ4: για το 2ο μοτέρ.
12 | ENB: για το 2ο μοτέρ.
13, 14 | Εδώ συνδέεται το 2ο μοτέρ.

### Δραστηριότητα 2

Υλοποιήστε το παρακάτω κύκλωμα. Ο βραχυκυκλωτήρας (3) πρέπει να παραμείνει στη θέση του, αν η εξωτερική τροφοδοσία είναι έως 12V.


### Δραστηριότητα 3

Γράψτε το πρόγραμμα:

// οι συνδέσεις των pins του arduino
// με τα pins της πλακέτας ελέγχου του μοτέρ (L298N H-Bridge)

const int enA = 10;

const int in1 = 9;

const int in2 = 8;

void setup()

{

pinMode(enA, OUTPUT);

pinMode(in1, OUTPUT);

pinMode(in2, OUTPUT);

}

void loop()

{

// πήγαινε προς τη μία κατεύθυνση

digitalWrite(in1, HIGH);

digitalWrite(in2, LOW);

// ορισμός της ταχύτητας από το εύρος 0~255

analogWrite(enA, 240);

delay(2000);

// πήγαινε προς την άλλη κατεύθυνση

digitalWrite(in1, LOW);

digitalWrite(in2, HIGH);

// ορισμός της ταχύτητας από το εύρος 0~255

analogWrite(enA, 220);

delay(2000);

}

### Δραστηριότητα 4

Προσθέστε τον 2ο κινητήρα στην πλακέτα ελέγχου και τροποποιήστε το πρόγραμμα, έτσι ώστε οι 2 κινητήρες να κινούνται ταυτόχρονα.

### Επεκτάσεις

In-Depth: Interface L298N DC Motor Driver Module with Arduino (https://lastminuteengineers.com/l298n-dc-stepper-driver-arduino-tutorial/)

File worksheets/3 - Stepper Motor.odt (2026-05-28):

# Φύλλο Εργασίας 3

# Βηματικός Κινητήρας Stepper Motor

## Δραστηριότητα 1

Μπείτε στο In-Depth: Interface DRV8825 Stepper Motor Driver Module with Arduino (https://lastminuteengineers.com/drv8825-stepper-motor-driver-arduino-tutorial/) και διαβάστε τα βασικά χαρακτηριστικά του DRV8825.

## Δραστηριότητα 2

Μελετήστε την παράγραφο “Wiring a DRV8825 Stepper Motor Driver to an Arduino” και κάντε το κύκλωμα, όπως φαίνεται και στην παρακάτω εικόνα.


## Δραστηριότητα 3

Προσαρμόστε την ψύκτρα, όπως περιγράφεται στην παράγραφο “Cooling System – Heatsink”.

## Δραστηριότητα 4

Για τον περιορισμό του μέγιστου ρεύματος, ακολουθήστε τη 2η μέθοδο που περιγράφεται στη διαδικασία “Current limiting”.

## Δραστηριότητα 5

Εκτελέστε το πρόγραμμα στο Παράδειγμα 1, όπως φαίνεται και παρακάτω.

// Define pin connections & motor's steps per revolution

const int dirPin = 2;

const int stepPin = 3;

const int stepsPerRevolution = 200;

void setup()

{

// Declare pins as Outputs

pinMode(stepPin, OUTPUT);

pinMode(dirPin, OUTPUT);

}

void loop()
{

// Set motor direction clockwise

digitalWrite(dirPin, HIGH);

// Spin motor slowly

for (int x = 0; x < stepsPerRevolution; x++) {

digitalWrite(stepPin, HIGH);

delayMicroseconds(2000);

digitalWrite(stepPin, LOW);

delayMicroseconds(2000);

}

delay(1000); // Wait a second

// Set motor direction counterclockwise

digitalWrite(dirPin, LOW);

// Spin motor quickly

for (int x = 0; x < stepsPerRevolution; x++) {

digitalWrite(stepPin, HIGH);

delayMicroseconds(1000);

digitalWrite(stepPin, LOW);

delayMicroseconds(1000);

}

delay(1000); // Wait a second

}

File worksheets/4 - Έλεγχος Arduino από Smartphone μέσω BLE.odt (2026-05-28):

# Φύλλο Εργασίας 4

# Έλεγχος Arduino από Smartphone μέσω BLE

Στο σενάριο αυτό θα φτιάξουμε μια εφαρμογή για Android με το App Inventor, που θα επικοινωνεί με το Arduino Uno R4 WiFi μέσω BLE (Bluetooth Low Energy) και θα στέλνει δεδομένα στο arduino. Σκοπός είναι να χρησιμοποιηθεί το κινητό σαν τηλεχειριστήριο για να ελέγχει το arduino.

Συνοπτικά τα βήματα που περιγράφονται αναλυτικά στη Δραστηριότητα 1 είναι τα εξής:

Για το κινητό:

1. Δημιουργία των απαραίτητων UUID (πχ εδώ: https://www.uuidgenerator.net/)
2. Εισαγωγή της επέκτασης (Extension) BluetoothLE στο App Inventor.
3. Σχεδίαση της διεπαφής (User Interface) στο App Inventor με το Designer.
4. Δημιουργία του κώδικα (Blocks) στο App Inventor.

Για το arduino:

1. Εγκατάσταση της βιβλιοθήκης ArduinoBLE στο Arduino IDE, μέσω του Διαχειριστή Βιβλιοθήκης.
2. Δημιουργία και φόρτωση του sketch στο Arduino IDE.

Για το BLE και τις διαφορές του από το Bluetooth Classic διαβάστε εδώ: https://docs.arduino.cc/learn/communication/bluetooth/

## Δραστηριότητα 1

Ακολουθήστε τις αναλυτικές οδηγίες και υλοποιήστε το project που βρίσκεται εδώ:

https://projecthub.arduino.cc/Arduino_Genuino/connect-a-board-via-ble-with-a-app-on-mit-app-inventor-03663e

## Δραστηριότητα 2

Επεκτείνετε την προηγούμενη δραστηριότητα, έτσι ώστε να στέλνονται επιπλέον 4 μεταβλητές από το κινητό στο arduino.

1. Για το σκοπό αυτό πρέπει να δημιουργήσετε επιπλέον 1 charasteristic για κάθε νέα μεταβλητή.
2. Για κάθε νέα μεταβλητή, προσθέστε ένα νέο στοιχείο στο App Inventor (πχ 2 slider και 2 checkbox).
3. Εμφανίστε τις τιμές όλων των μεταβλητών στο Serial Monitor του Arduino.

## Δραστηριότητα 3

Επεκτείνετε το προηγούμενο project με τους 2 κινητήρες DC, έτσι ώστε να τους ελέγχετε από το κινητό.

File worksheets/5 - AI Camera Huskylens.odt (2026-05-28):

# Φύλλο Εργασίας 5

# AI Camera Huskylens

## Δραστηριότητα 1

Μπείτε στο https://wiki.dfrobot.com/HUSKYLENS_V1.0_SKU_SEN0305_SEN0336 και μελετήστε τις ενότητες 1.Introduction, 2.Specification και 3.Board Overview

### Ερωτήσεις

Αντιστοιχίστε τις παρακάτω στήλες, που αναφέρονται στους αλγόριθμους που υλοποιεί η κάμερα:

1. | face recognition | | α. παρακολούθηση αντικειμένου
2. | object tracking | | β. αναγνώριση χρώματος
3. | object recognition | | γ. αναγνώριση προσώπου
4. | line tracking | | δ. αναγνώριση ετικέτας
5. | color recognition | | ε. αναγνώριση αντικειμένου
6. | tag recognition | | ζ. ακολουθία γραμμής
7. | object classification | | η. ταξινόμηση αντικειμένου

## Δραστηριότητα 2

Μελετήστε την ενότητα 7.Functions Introduction και πειραματιστείτε με τις λειτουργίες Face Recognition και Tag Recognition.

## Δραστηριότητα 3

Μελετήστε την ενότητα 8. Arduino Tutorial και εγκαταστήστε στο Arduino IDE τη βιβλιοθήκη σύμφωνα με τις οδηγίες της παραγράφου 8.1.

## Δραστηριότητα 4

Ξεκινήστε το Project 1: Read Position Data.

Αρχικά συνδέστε την κάμερα στο Arduino με τη μέθοδο I2C Mode.

Συνεχίστε με την υλοποίηση της άσκησης, ως εξής:

1. Φορτώστε τον προτεινόμενο κώδικα στο Arduino.
2. Ανοίξτε το Serial Monitor στο Arduino IDE και επιβεβαιώστε ότι εμφανίζει τις συντεταγμένες του αντικειμένου που αναγνωρίζει, ανάλογα με τον επιλεγμένο τρόπο λειτουργίας (mode).


## Δραστηριότητα 5

Κατασκευή πινακίδας: Εκτυπώστε σε μέγεθος χαρτιού Α3 τη διπλανή εικόνα (που είναι το πρώτο από τα λεγόμενα April Tags) και κολλήστε την σε ένα χαρτόνι.

## Δραστηριότητα 6

Χρησιμοποιήστε τον αλγόριθμο “Tag Recognition” για να εκπαιδεύσετε την κάμερα έτσι ώστε να αναγνωρίζει την πινακίδα που φτιάξατε.

Συνοπτικά:

1. Γυρίστε το κουμπί της κάμερας HuskyLens στη λειτουργία "Tag Recognition".
2. Στοχεύστε την πινακίδα με το Tag από κοντινή απόσταση (περίπου 1 μέτρο) και πατήστε (και κρατήστε πατημένο) το κουμπί εκμάθησης. Η κάμερα θα το πλαισιώσει με ένα έγχρωμο τετράγωνο και θα του δώσει ένα ID.
3. Απομακρυνθείτε σταδιακά συνεχίζοντας τη διαδικασία εκμάθησης από διάφορες γωνίες.
4. Στο τέλος η κάμερα πρέπει να μπορεί να αναγνωρίζει την πινακίδα από διάφορες γωνίες και αποστάσεις.

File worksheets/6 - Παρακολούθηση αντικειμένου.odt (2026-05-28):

# Φύλλο Εργασίας 6

# Παρακολούθηση αντικειμένου

## (Συνέχεια από το προηγούμενο φύλλο εργασίας 5, δραστηριότητα 6 “Αναγνώριση πινακίδας (Tag)”)

## Δραστηριότητα 7

Συνδέστε την κάμερα HuskyLens στο Arduino μέσω I2C.

Συνδέστε ένα μοτέρ servo στο Arduino, όπως στο φύλλο εργασίας 1.

Προσαρμόστε την κάμερα HuskyLens πάνω στο μοτέρ.

## Δραστηριότητα 8

Εκπαιδεύστε την κάμερα στην αναγνώριση του πρώτου April Tag, όπως στη Δραστηριότητα 6.

## Δραστηριότητα 9

Αναπτύξτε ένα πρόγραμμα που θα αναγνωρίζει την πινακίδα με το tag, και θα περιστρέφει το μοτέρ έτσι ώστε η κάμερα να κοιτάζει κατευθείαν στην πινακίδα.

Υπόδειξη: Η κάμερα μόλις αναγνωρίσει την πινακίδα, επιστρέφει τις συντεταγμένες του τετραγώνου που περικλείει το Tag, έτσι όπως φαίνεται στην οθόνη του HuskyLens (xCenter και yCenter). Οι οθόνη έχει διαστάσεις 320x240 pixel, οπότε το κεντρικό σημείο είναι στη θέση x=160.

Άρα αν xCenter είναι μεγαλύτερο από 160, τότε το μοτέρ πρέπει να περιστραφεί προς τα δεξιά, ενώ αν είναι μικρότερο από 160 προς τα αριστερά.

Ενδεικτική λύση:

#include <Servo.h>

Servo myservo; // create servo object to control a servo

int pos = 0; // variable to store the servo position

#include "HUSKYLENS.h"

HUSKYLENS huskylens;

//HUSKYLENS green line >> SDA; blue line >> SCL

int ID0 = 0; //not learned results. Grey result on HUSKYLENS screen

int ID1 = 1; //first learned results. colored result on HUSKYLENS screen

void setup()

{

Serial.begin(115200);

Wire.begin();

while (!huskylens.begin(Wire))

{

Serial.println(F("Begin failed!"));

Serial.println(F("1.Please recheck the \"Protocol Type\" in HUSKYLENS (General Settings>>Protocol Type>>I2C)"));

Serial.println(F("2.Please recheck the connection."));

delay(100);

}

// the algorithm on HUSKYLENS

huskylens.writeAlgorithm(ALGORITHM_TAG_RECOGNITION);

myservo.attach(6); // attaches the servo on pin 6 to the servo object

pos = 90;

myservo.write(pos); // αρχική τοποθέτηση του servo στη μέση

}

void loop()

{

//request blocks tagged ID == ID1 from HUSKYLENS

if (huskylens.requestBlocks(ID1))

{

if ( huskylens.count(ID1)>0 ) // αν βρέθηκε μια πινακίδα

{

HUSKYLENSResult result = huskylens.get(ID1, 0);

int x = result.xCenter;

// αντί για τη μέση τιμή (160) χρησιμοποιούμε τις τιμές 135

// και 185, για να δώσουμε μια ανοχή και να αποφύγουμε τις

// συνεχείς κινήσεις του μοτέρ

if( x<135 )

{

// κινήσου προς τα αριστερά (μέχρι 180 μοίρες)

if( pos<180 ) pos++;

else pos=180;

}

else if( x>185 )

{

// κινήσου προς τα δεξιά (μέχρι 0 μοίρες)

if( pos>0 ) pos--;

else pos=0;

}

myservo.write(pos);

delay(15);

}

}

}

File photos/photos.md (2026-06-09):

## Φωτογραφίες από τη δημιουργία του έργου.
















































photo48a













photo61a
photo61b
photo61c
























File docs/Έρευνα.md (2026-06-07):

# **Έρευνα**

## **α. Μελέτη υπάρχουσας κατάστασης**

Η ρύπανση από πλαστικά αποτελεί ένα από τα σοβαρότερα περιβαλλοντικά προβλήματα παγκοσμίως. Ιδιαίτερη ανησυχία προκαλούν τα μικροπλαστικά, δηλαδή πλαστικά σωματίδια μεγέθους μικρότερου των 5 χιλιοστών, τα οποία προέρχονται είτε από τη διάσπαση μεγαλύτερων πλαστικών αντικειμένων, είτε από βιομηχανικά και καταναλωτικά προϊόντα.

Έρευνες έχουν δείξει ότι μικροπλαστικά εντοπίζονται πλέον σε ποτάμια, λίμνες, θάλασσες, στο έδαφος, στην ατμόσφαιρα, αλλά και σε ζωντανούς οργανισμούς.

Η παρουσία τους είναι ιδιαίτερα ανησυχητική, καθώς:

- δεν αποδομούνται εύκολα
- μεταφέρονται σε μεγάλες αποστάσεις μέσω του νερού
- εισέρχονται στην τροφική αλυσίδα
- μπορούν να μεταφέρουν τοξικές ουσίες

Τα ποτάμια αποτελούν βασικές οδούς μεταφοράς πλαστικών απορριμμάτων από τις αστικές και αγροτικές περιοχές προς τη θάλασσα. Για τον λόγο αυτό, η παρέμβαση σε αυτά θεωρείται ιδιαίτερα σημαντική, καθώς η πρόληψη είναι πιο αποτελεσματική από την απορρύπανση όταν τα σωματίδια φτάσουν στο θαλάσσιο περιβάλλον.

### **Τι δείχνουν οι έρευνες**

1\. Βρίσκονται σε νερό,σε ιζήματα και στον αέρα γύρω από τα ποτάμια  
Σε μεγάλους ποταμούς όπως ο Γάγγης, εντοπίζονται μικροπλαστικά όχι μόνο στο νερό αλλά και στα ιζήματα του ποταμού και ακόμη μέσω καθίζησης από τον αέρα στην επιφάνεια του νερού. ([Rivers contain hidden sinks and sources of microplastics | ScienceDaily](https://www.sciencedaily.com/releases/2023/09/230925124804.htm))

2\. Τα ποτάμια μεταφέρουν μικροπλαστικά στη θάλασσα  
Μελέτες δείχνουν ότι ποτάμια λειτουργούν σαν «αυτοκινητόδρομοι» για τα μικροπλαστικά, τα οποία κινούνται με τη ροή του νερού και τελικά εκβάλλουν στη θάλασσα, όπου συσσωρεύονται. ([Rivers Are a Highway for Microplastics into the Ocean - Eos](https://eos.org/articles/rivers-are-a-highway-for-microplastics-into-the-ocean))

3\. Συγκέντρωση σε ιζήματα και πιθανή παραμονή για χρόνια  
Μικροπλαστικά μπορούν να παγιδευτούν και να μείνουν για μεγάλο χρονικό διάστημα στα ιζήματα του ποταμού (μέχρι και αρκετά χρόνια), αντί να μεταφέρονται αμέσως στη θάλασσα, αυξάνοντας την πιθανότητα να εισέλθουν στην τροφική αλυσίδα των οργανισμών που ζουν εκεί. ([Microplastic pollution lingers in rivers for years before entering oceans | NSF](https://www.nsf.gov/news/microplastic-pollution-lingers-rivers-years))

### **Πηγές ρύπανσης**

Οι κύριες πηγές που τροφοδοτούν τα ποτάμια με μικροπλαστικά είναι:

- Αστικά λύματα και απορροές από πόλεις
- Λύματα πλυντηρίων ρούχων και άλλες καθημερινές δραστηριότητες
- Κατάλοιπα πλαστικών από αγροτική και βιομηχανική χρήση
- Απόθεση από τον αέρα πάνω στο νερό

### **Περιβαλλοντικές και υγειονομικές επιπτώσεις**

- Τα μικροπλαστικά μπορούν να εισέλθουν στην τροφή ψαριών και άλλων υδρόβιων οργανισμών. ([Μικροπλαστικά: «Παραφορτωμένα» όλα τα είδη στα ποτάμια που εκβάλλουν στη Μεσόγειο |](https://www.in.gr/2023/11/17/in-science/perivallon-b-science/mikroplastika-parafortomena-ola-ta-eidi-sta-potamia-pou-ekvalloun-sti-mesogeio) [in.gr](http://in.gr))
- Η κατάσταση επιδεινώνεται. ([Ευρώπη: Ανησυχητικές οι συγκεντρώσεις μικροπλαστικών στους μεγάλους ποταμούς | in.gr](https://www.in.gr/2025/04/07/in-science/perivallon-b-science/eyropi-anisyxitika-ta-pososta-mikroplastikon-stous-megalous-potamous/))

### **Υπάρχουσες λύσεις**

Σήμερα χρησιμοποιούνται διάφορες τεχνολογίες για την αντιμετώπιση της πλαστικής ρύπανσης:

- Σταθερά συστήματα συλλογής  
Πλωτά φράγματα, φίλτρα και «παγίδες» που συγκρατούν μεγάλα πλαστικά και μέρος των μικροπλαστικών. Τοποθετούνται σε ποτάμια ή αποχετευτικά δίκτυα και συγκρατούν απορρίμματα που επιπλέουν στην επιφάνεια του νερού.

- Μεγάλα αυτόνομα σκάφη καθαρισμού  
Χρησιμοποιούνται κυρίως σε λιμάνια ή μεγάλες υδάτινες επιφάνειες και έχουν υψηλό κόστος.

- Συστήματα φιλτραρίσματος σε εγκαταστάσεις επεξεργασίας νερού  
Σύγχρονες μονάδες (πχ βιολογικού καθαρισμού) μπορούν να αφαιρούν έως και 90-99% των μικροπλαστικών πριν τα λύματα καταλήξουν στο ποτάμι. Εφαρμόζονται μόνο σε οργανωμένες υποδομές.

Μελετώντας αυτές τις λύσεις, παρατηρήσαμε ότι:

- είναι ακριβές
- απαιτούν εξειδικευμένες εγκαταστάσεις
- δεν είναι εύκολα υλοποιήσιμες σε μικρά ποτάμια και σε τοπικές κοινότητες
- συχνά δεν προσφέρουν ευέλικτο έλεγχο σε διαφορετικά βάθη νερού

## **β. Σαφής ορισμός προβλήματος - ανάγκης**

### **Το πρόβλημα**

Το πρόβλημα της ρύπανσης από μικροπλαστικά είναι πλέον τόσο εκτεταμένο, που πρέπει να βρεθούν οικονομικές, ευέλικτες και εύκολα υλοποιήσιμες τεχνολογικές λύσεις, που να μπορούν να συμβάλλουν στη μείωση της πλαστικής ρύπανσης σε ποτάμια και λίμνες, πριν τα πλαστικά σωματίδια μεταφερθούν στη θάλασσα.

Η δυσκολία εντοπίζεται στο ότι:

- τα πλαστικά σωματίδια μπορούν να βρίσκονται σε διαφορετικά βάθη
- η συλλογή τους απαιτεί ελεγχόμενη πρόσβαση στο νερό
- οι περισσότερες υπάρχουσες λύσεις έχουν υψηλό κόστος
- απουσιάζουν ανοιχτές και χαμηλού κόστους εφαρμογές

### **Η ανάγκη**

Χρειάζεται ένα σύστημα που να είναι:

- χαμηλού κόστους
- επεκτάσιμο
- εύκολο στην κατασκευή
- αυτόνομο
- ενεργειακά ανεξάρτητο, με χρήση ανανεώσιμων πηγών ενέργειας
- βασισμένο σε ανοιχτές τεχνολογίες
- κατάλληλο για εκπαιδευτική χρήση
- ικανό να πραγματοποιεί ελεγχόμενο φιλτράρισμα σε διαφορετικά βάθη

### **Η δική μας πρόταση**

Για να καλύψουμε αυτή την ανάγκη, σχεδιάσαμε ένα αυτόνομο ρομποτικό σκάφος ελεγχόμενο από Arduino, το οποίο:

- κινείται σε υδάτινες επιφάνειες
- πραγματοποιεί καθαρισμό με φιλτραρισμένη άντληση νερού
- ρυθμίζει το βάθος λειτουργίας της αντλίας
- χρησιμοποιεί ανοιχτό hardware και software

Το έργο μας στοχεύει στη δημιουργία μιας πρακτικής και εύκολης λύσης για την προστασία του περιβάλλοντος.



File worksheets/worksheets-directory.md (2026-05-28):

Εδώ βρίσκονται τα φύλλα εργασίας για τη δημιουργία του έργου.

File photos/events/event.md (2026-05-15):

## Φωτογραφίες από την παρουσίαση του έργου στη 3η Γιορτή Δημιουργίας και Ψηφιακών Δεξιοτήτων "Ο Θε-ΤΑΛΩΣ συναντά τα e-trikala 3" και από την παρουσίαση στο σχολείο














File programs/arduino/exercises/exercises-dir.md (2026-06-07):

Εδώ περιέχονται διάφορα βοηθητικά προγράμματα, επιμέρους ασκήσεις και λύσεις των φύλλων εργασίας.

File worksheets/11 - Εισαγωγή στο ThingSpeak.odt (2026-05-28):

# Φύλλο Εργασίας 11

# Εισαγωγή στο ThingSpeak

Πηγές:

https://www.mathworks.com/help/thingspeak/getting-started-with-thingspeak.html

Το ThingSpeak είναι μια πλατφόρμα στο διαδίκτυο όπου μπορούμε να στείλουμε δεδομένα που αποθηκεύονται στο νέφος (cloud), αναπτύσσοντας έτσι εφαρμογές Internet of Things.

Αρχικά, κάνουμε λογαριασμό στο Thingspeak.com.

Κατόπιν:

- Μπαίνουμε στο λογαριασμό μας στο Thingspeak.com και δημιουργούμε ένα νέο κανάλι (New Channel).
- Δίνουμε ένα όνομα στο κανάλι.
- Επιλέγουμε τα 5 πρώτα πεδία και τα ονομάζουμε όπως στον πίνακα:

Πεδίο | Όνομα πεδίου | Περιγραφή
field1 | Lat | Γεωγραφικό πλάτος (Latitude)
field2 | Lon | Γεωγραφικό μήκος (Longitude)
field3 | Sog | Ταχύτητα ως προς το έδαφος (Speed over ground) σε knots
field4 | Cog | Πορεία ως προς το έδαφος (Course over ground) σε degrees
field5 | Satellites | Αριθμός δορυφόρων που χρησιμοποιήθηκαν

Για να γράψουμε δεδομένα στο κανάλι, χρησιμοποιούμε το REST API ως εξής:

Σε έναν browser γράφουμε στη γραμμή διεύθυνσης:

https://api.thingspeak.com/update.json?api_key=<write_api_key>&field1=123&field2=222&field3=333&field4=444&field5=555

όπου αντικαθιστούμε το <write_api_key> με τον κωδικό που βρίσκουμε στην καρτέλα “API Keys” του καναλιού μας, και συμπληρώνουμε τα πεδία και τις τιμές που θέλουμε να αποθηκεύσουμε.

Ελέγχουμε τις τιμές στην καρτέλα “Private View” του καναλιού μας.

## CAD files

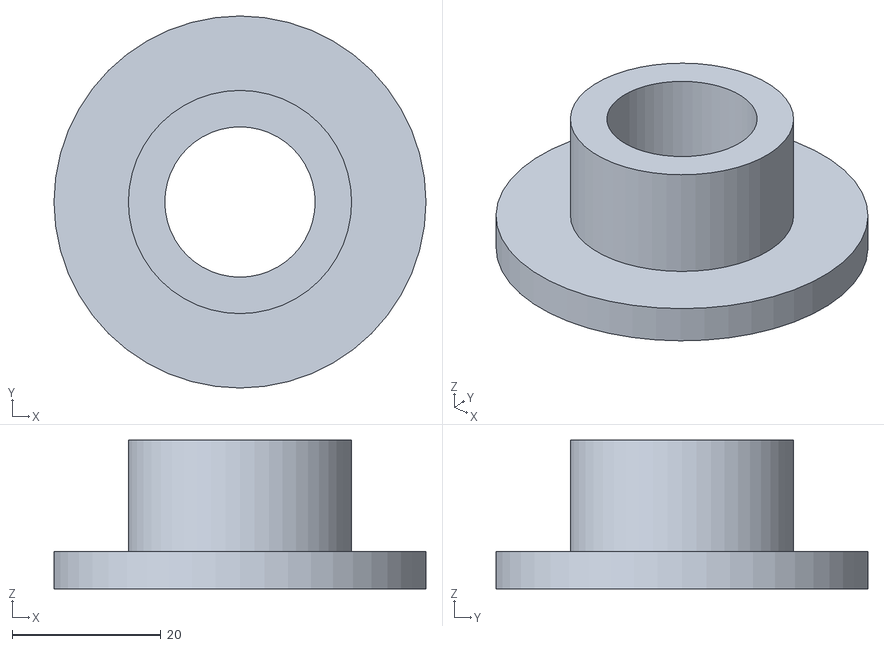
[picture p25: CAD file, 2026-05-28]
design/3D-objects/MoufaFiltrou.stl
50.0 x 50.0 x 20.0

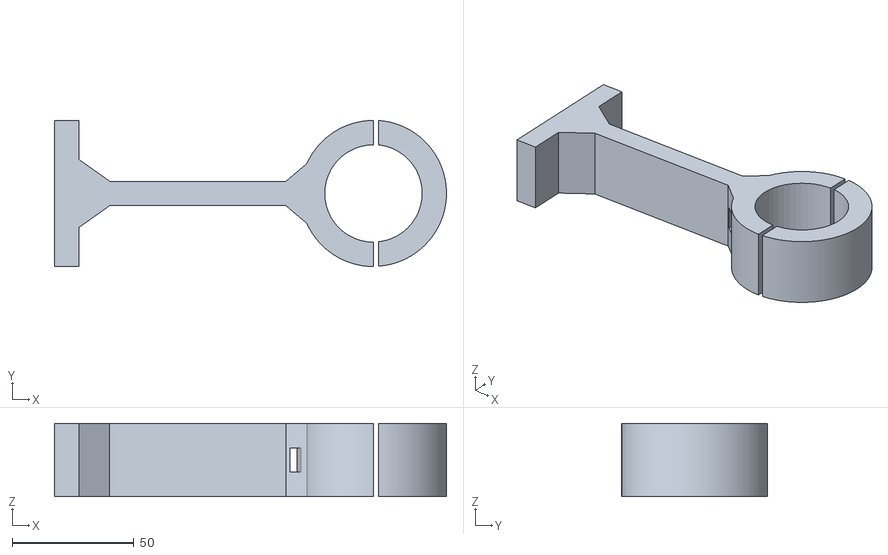
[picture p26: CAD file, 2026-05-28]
design/3D-objects/BasiMoter.stl
161.0 x 60.0 x 30.0

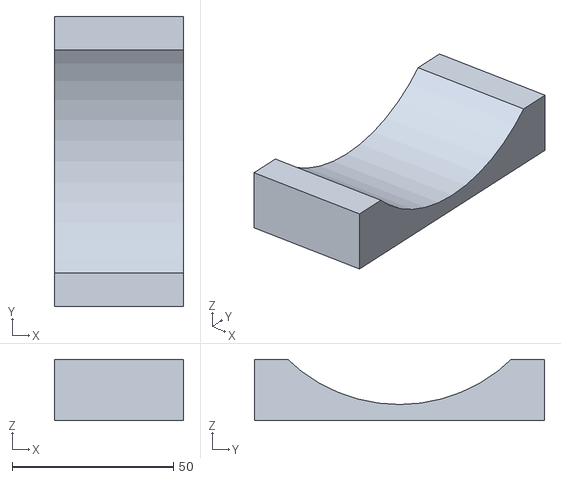
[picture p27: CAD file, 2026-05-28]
design/3D-objects/BasiPlotiron.stl
40.0 x 90.0 x 19.0

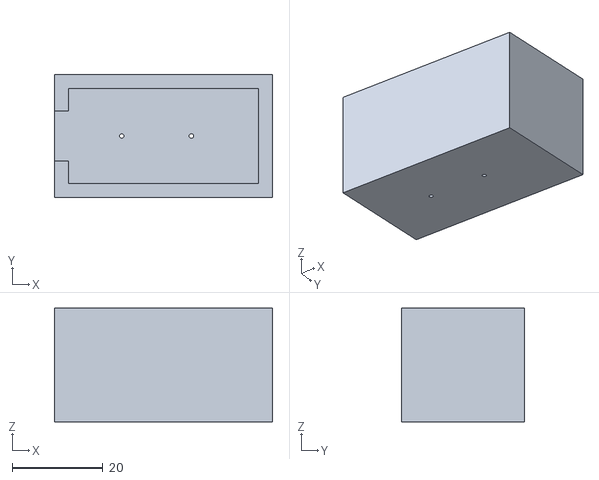
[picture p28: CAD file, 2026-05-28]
design/3D-objects/ServoMotorBase.stl
48.0 x 27.0 x 25.0

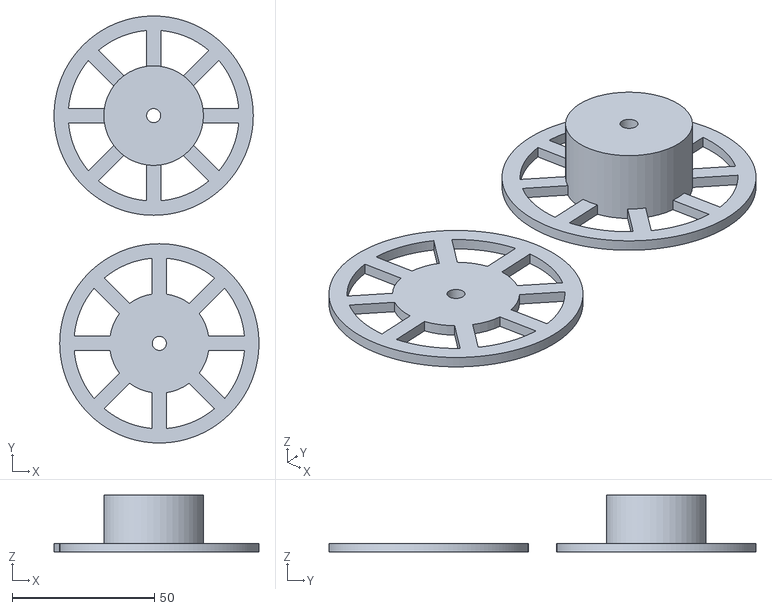
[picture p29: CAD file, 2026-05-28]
design/3D-objects/Troxalia.stl
72.0 x 150.0 x 20.0

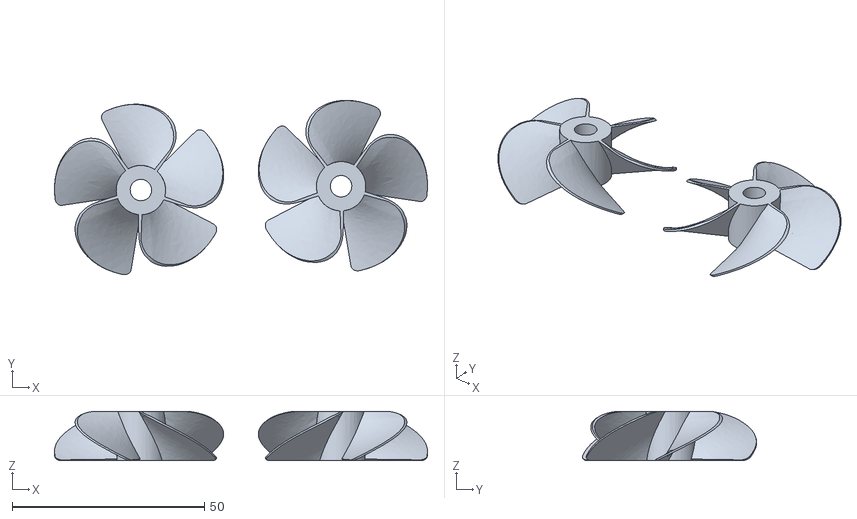
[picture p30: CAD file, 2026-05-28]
design/3D-objects/Propellers.stl
97.1 x 45.4 x 12.9

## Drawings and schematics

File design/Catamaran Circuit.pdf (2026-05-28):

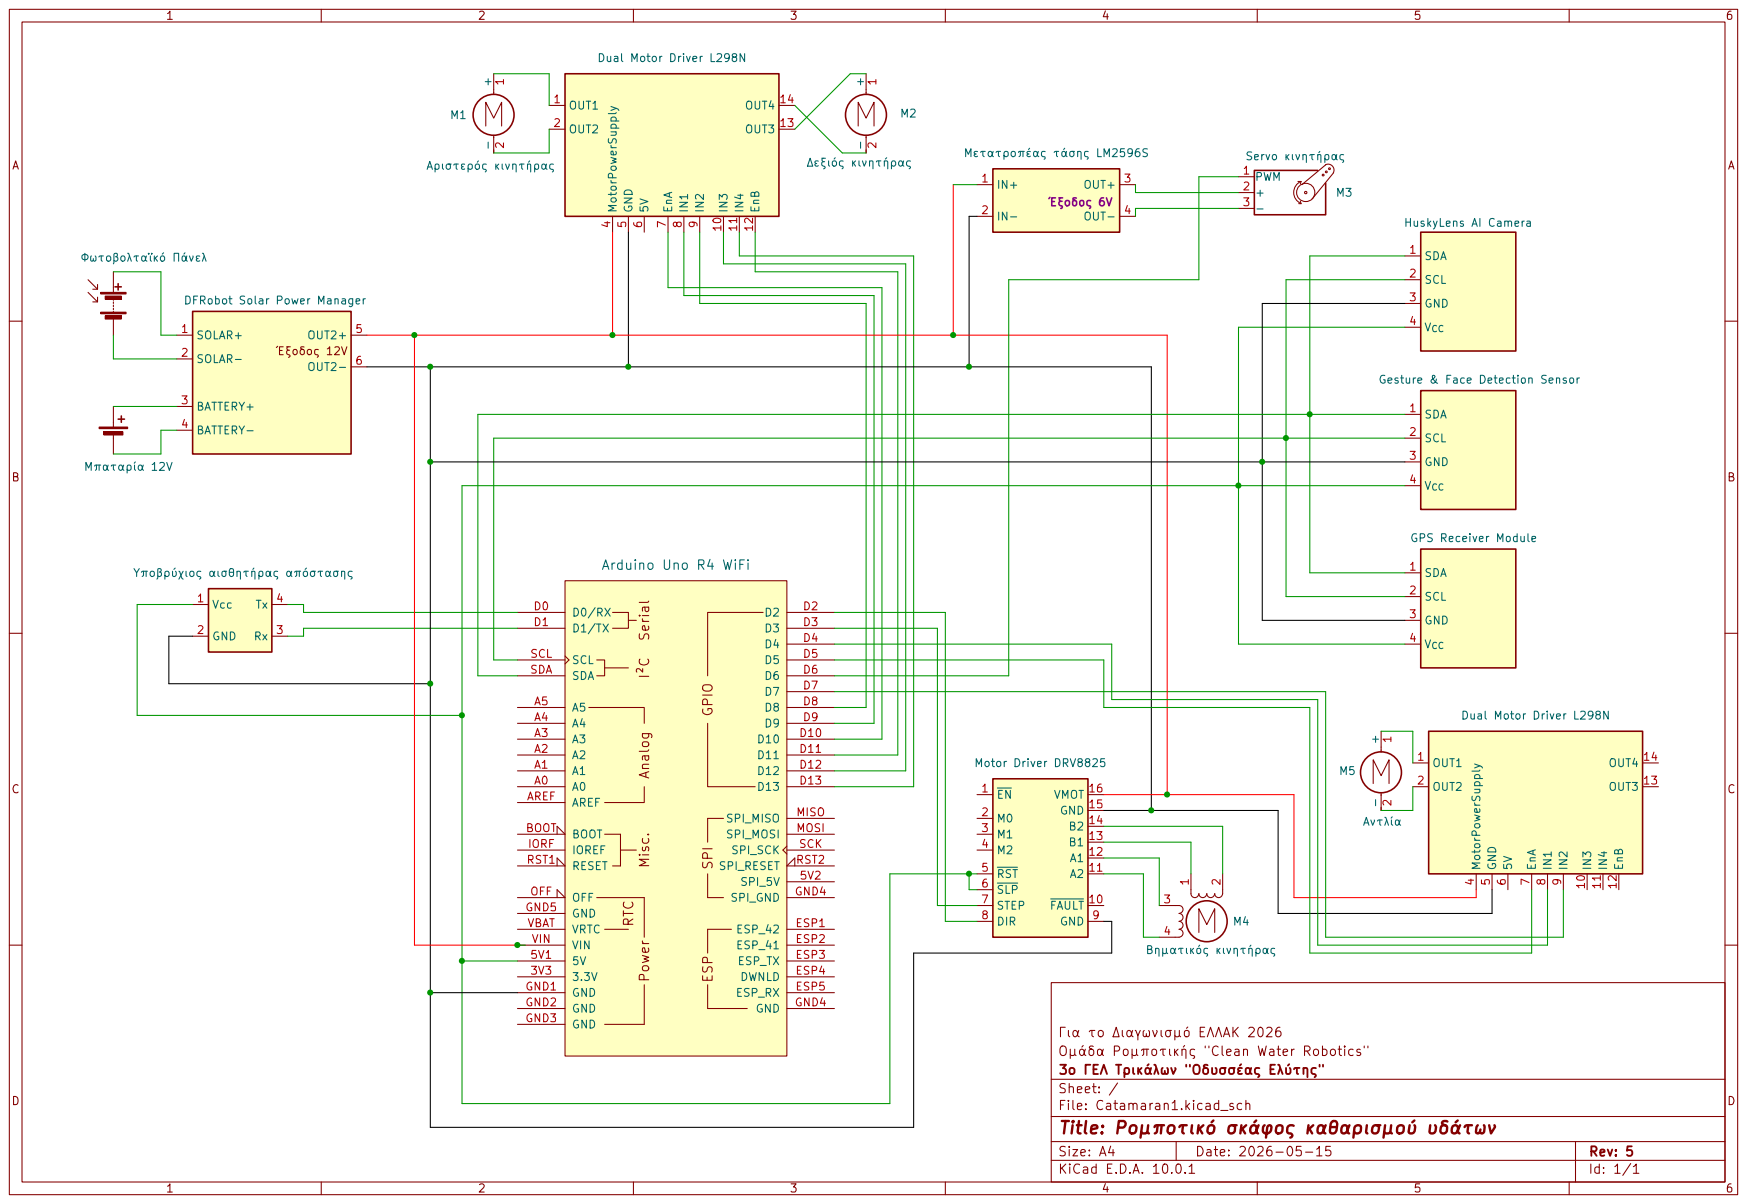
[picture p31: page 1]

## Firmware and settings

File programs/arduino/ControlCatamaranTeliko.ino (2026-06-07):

/* ******************************************************************************
 * Πρόγραμμα ελέγχου του καταμαράν
 * 
 * 1 - Έλεγχος 2 Κινητήρων DC με πλακέτα L298N (H-Bridge)
 * 2 - Λήψη εντολών ελέγχου από εφαρμογή App Inventor 
 *     μέσω BLE (Bluetooth Low Energy) 
 * 3 - Έλεγχος του σκάφους με κάμερα χειρονομιών
 * 4 - Ενσωμάτωση κάμερας HUSKYLENS
 * 5 - Ενσωμάτωση κινητήρα servo για περιστροφή της HUSKYLENS
 * 6 - Παρακολούθηση πινακίδας με την HUSKYLENS και έλεγχος του σκάφους ανάλογα
 * 7 - Εμφάνιση εικονιδίων στο LED matrix του Arduino R4
 * 8 - Έλεγχος αντλίας καθαρισμού υδάτων με πλακέτα L298N (H-Bridge)
 * 9 - Έλεγχος τροχαλίας και βηματικού κινητήρα για το ανεβοκατέβασμα της αντλίας
 * 10 - Σύνδεση δέκτη GPS και αποστολή συντεταγμένων θέσης στο ThingSpeak μέσω WiFi
 * 
 * 3ο ΓΕΛ Τρικάλων "Οδυσσέας Ελύτης"
 * Ομάδα Ρομποτικής "Clean Water Robotics"
 * Για τον 8ο Διαγωνισμό ΕΛΛΑΚ 2026
 * 
 * ******************************************************************************/

// Εικονίδια για LED matrix
#include "Arduino_LED_Matrix.h"
ArduinoLEDMatrix matrix;
const uint32_t forward[] = {
  0x400e01f,
  0x3f80e00,
  0xe00e00e0
};
const uint32_t backward[] = {
  0xe00e00e,
  0xe03f81,
  0xf00e0040
};
const uint32_t stop[] = {
  0x2642f41f,
  0x830c3fc1,
  0xf8090090
};
const uint32_t happy[] = {
  0x19819,
  0x80000001,
  0x81f8000
};



#include <ArduinoBLE.h>

// Define a custom BLE service and characteristic
BLEService controlService("e9ef1f54-4708-4927-930f-191b2d624cab");  // εδώ δημιουργήσαμε το δικό μας UUID
// στα παρακάτω χαρακτηριστικά, τροποποιήσαμε μόνο τον 8ο χαρακτήρα του UUID, για ευκολία
// Κάθε χαρακτηριστικό αντιστοιχεί σε μια τιμή που θέλουμε να λάβουμε
BLEShortCharacteristic var1Characteristic("e9ef1f55-4708-4927-930f-191b2d624cab", BLEWrite | BLEWriteWithoutResponse | BLERead | BLENotify);
BLEShortCharacteristic var2Characteristic("e9ef1f56-4708-4927-930f-191b2d624cab", BLEWrite | BLEWriteWithoutResponse | BLERead | BLENotify);
BLEUnsignedCharCharacteristic var3Characteristic("e9ef1f57-4708-4927-930f-191b2d624cab", BLEWrite | BLEWriteWithoutResponse);
BLEUnsignedCharCharacteristic var4Characteristic("e9ef1f58-4708-4927-930f-191b2d624cab", BLEWrite | BLEWriteWithoutResponse);
BLEUnsignedCharCharacteristic var5Characteristic("e9ef1f59-4708-4927-930f-191b2d624cab", BLEWrite | BLEWriteWithoutResponse);

// pins ελέγχου του μοτέρ 1
const int enA = 10;
const int in1 = 9;
const int in2 = 8;
// pins ελέγχου του μοτέρ 2
const int enB = 11;
const int in3 = 13;
const int in4 = 12;

// Define pin connections & stepper motor's steps per revolution
const int dirPin = 2;
const int stepPin = 3;
//const int stepsPerRevolution = 200; // για το συγκεκριμένο μοτέρ
const int fullLength = 800;   // 800 = 4 * 200 βήματα, άρα 4 πλήρεις περιστροφές
int strofes=0;        // για να μετράμε τα βήματα του stepper motor

// Η κλίμακα ταχύτητας των μοτέρ είναι από -4 έως 4, όπως φαίνεται στον πίνακα:
/*****************************
 * Κλίμακα  ->  Ταχύτητα (PWM)
 *      4   ->  μπροστά 255
 *      3   ->  μπροστά 230
 *      2   ->  μπροστά 205
 *      1   ->  μπροστά 180
 *      0   ->  0
 *     -1   ->  πίσω 180
 *     -2   ->  πίσω 205
 *     -3   ->  πίσω 230
 *     -4   ->  πίσω 255
 *****************************/

short leftSpeed = 0;
short rightSpeed = 0;

// για εντολή ενεργοποίησης του ελέγχου του σκάφους με χειρονομίες
bool enableGestures = false;
// για εντολή ενεργοποίησης της παρακολούθησης της πινακίδας
bool followTag = false;
// για εντολή καθαρισμού του νερού
bool cleanWater = false;
bool cleaning=false;    // η κατάσταση καθαρισμού

// για εντοπισμό της πινακίδας
bool found=false;

#include "DFRobot_GestureFaceDetection.h"
// Define the device ID for the GestureFaceDetection sensor
#define DEVICE_ID 0x72
// Create an instance of DFRobot_GestureFaceDetection_I2C with the specified device ID
DFRobot_GestureFaceDetection_I2C gfd(DEVICE_ID);
// Buffer for formatted output
char str[100];



#include <Servo.h>
Servo myservo;  // create servo object to control the servo
const int servoPin = 6;
int pos = 0;    // variable to store the servo position

#include "HUSKYLENS.h"
HUSKYLENS huskylens;
//HUSKYLENS green line >> SDA; blue line >> SCL
int ID0 = 0; //not learned results. Grey result on HUSKYLENS screen
int ID1 = 1; //first learned results. colored result on HUSKYLENS screen


// για τον υποβρύχιο αισθητήρα απόστασης
unsigned char buffer_RTT[4] = {0};
uint8_t myCS;
#define COM 0x55
int distance = 0;



// GPS και αποστολή δεδομένων στο ThingSpeak μέσω WiFi
#include "DFRobot_GNSS.h"
#define I2C_COMMUNICATION  // use I2C for communication
DFRobot_GNSS_I2C gnss(&Wire ,GNSS_DEVICE_ADDR);

#include <WiFiS3.h>
#include "secrets.h"
#include <ThingSpeak.h> // always include thingspeak header file after other header files and custom macros

char ssid[] = SECRET_SSID;   // WiFi SSID (name) 
char pass[] = SECRET_PASS;   // WiFi password
int status = WL_IDLE_STATUS;
WiFiClient  client;

// η διεύθυνση του thingspeak
char server[] = "api.thingspeak.com";
unsigned long myChannelNumber = SECRET_CH_ID;
const char *myWriteAPIKey = SECRET_WRITE_APIKEY;
const char *myReadAPIKey = SECRET_READ_APIKEY;

// για μέτρηση του χρόνου
unsigned long currentTime;
unsigned long previousTime = 0;


void setup()
{
  matrix.begin();     // αρχικοποίηση LED matrix του Arduino R4

  // ορισμός pin
  pinMode(enA, OUTPUT);
  pinMode(in1, OUTPUT);
  pinMode(in2, OUTPUT);
  pinMode(enB, OUTPUT);
  pinMode(in3, OUTPUT);
  pinMode(in4, OUTPUT);
  pinMode(stepPin, OUTPUT);
  pinMode(dirPin, OUTPUT);
  pinMode(servoPin, OUTPUT);

  Serial.begin(115200);     // USB serial
  Serial1.begin(115200);    // hardware serial on pins 0,1, για τον υποβρύχιο αισθητήρα απόστασης

  // Initialize BLE
  if( !BLE.begin() )
  {
    Serial.println("Failed to start BLE.");
    Serial.println("Press Reset...");
    while(1)
      ;
  }
  else
  {
    Serial.println("Bluetooth ok!");
  }

  // Set the device name and advertise the service
  BLE.setLocalName("CatamaranPeripheral");
  BLE.setAdvertisedService(controlService);

  // Attach the characteristics to the service
  controlService.addCharacteristic(var1Characteristic);
  controlService.addCharacteristic(var2Characteristic);
  controlService.addCharacteristic(var3Characteristic);
  controlService.addCharacteristic(var4Characteristic);
  controlService.addCharacteristic(var5Characteristic);

  // Register the service with the BLE stack
  BLE.addService(controlService);

  // Set initial values for the characteristics
  var1Characteristic.writeValue(0);   // ταχύτητα του μοτέρ 1
  var2Characteristic.writeValue(0);   // ταχύτητα του μοτέρ 2
  var3Characteristic.writeValue(0);   // για ενεργοποίηση χειρονομιών (enableGestures)
  var4Characteristic.writeValue(0);   // για ενεργοποίηση παρακολούθησης πινακίδας (followTag)
  var5Characteristic.writeValue(0);   // για ενεργοποίηση καθαρισμού του νερού (cleanWater)

  // Start advertising the BLE service
  BLE.advertise();
  Serial.println("BLE Catamaran Peripheral is now advertising...");

  // Wait for the gesture sensor to start.
  delay(3000);
  // Initialize I2C communication
  gfd.begin(&Wire);
  while( !gfd.begin() )
  {
    Serial.println("Communication with Gesture Camera failed, please check connection...");
    delay(1000);
  }

  // κάμερα HUSKYLENS
  Wire.begin();
  while (!huskylens.begin(Wire))
  {
      Serial.println(F("Huskylens initialization failed..."));
      Serial.println(F("1.Please recheck the \"Protocol Type\" in HUSKYLENS (General Settings>>Protocol Type>>I2C)"));
      Serial.println(F("2.Please recheck the connection."));
      delay(100);
  }
  // ενεργοποίηση του αλγόριθμου αναγνώρισης πινακίδων (April Tags) του HUSKYLENS
  huskylens.writeAlgorithm(ALGORITHM_TAG_RECOGNITION);

  // servo
  myservo.attach(servoPin);  // attaches the servo on pin 6 to the servo object
  pos = 90;           // αρχική τοποθέτηση του servo στη μέση
  myservo.write(pos);
  delay(500);

  // GPS
  while( !gnss.begin() )
  {
    Serial.println("NO GNSS module found...");
    delay(1000);
  }
  gnss.enablePower();   // Enable gnss power 
  gnss.setGnss(eGPS_BeiDou_GLONASS);  // use gps + beidou + glonass
  gnss.setRgbOn();
  // gnss.disablePower();      // Disable GNSS, the data will not be refreshed after disabling  

  // Σύνδεση στο WiFi
  ConnectToWiFi();
  
  // Initialize ThingSpeak
  ThingSpeak.begin(client);
}


void loop()
{
  // Wait for a central device to connect
  BLEDevice central = BLE.central();

  if( central )
  {
    Serial.print("Connected to central: ");
    Serial.println(central.address());

    // Stay in loop while the central is connected
    while( central.connected() )
    {
      // έλεγχος του χρόνου για αποστολή στο ThingSpeak
      currentTime = millis();
      // συγχρονισμός με το ThingSpeak κάθε 60 sec
      if( currentTime - previousTime >= 60000 )
      {
        sendToThingSpeak();
        previousTime = currentTime;
      }

      // Check if the characteristics has been updated by the central
      if( var1Characteristic.written() )
      {
        // Read the new value from the characteristic
        short var1Value = var1Characteristic.value();
        UpdateSpeedMotor1(var1Value);
      }
      if( var2Characteristic.written() )
      {
        // Read the new value from the characteristic
        short var2Value = var2Characteristic.value();
        UpdateSpeedMotor2(var2Value);
      }
      if( var3Characteristic.written() )
      {
        // Read the new value from the characteristic
        unsigned char var3Value = var3Characteristic.value();
        if(var3Value==1)
        {
          enableGestures=true;
        }
        else
        {
          enableGestures=false;
        }
      }
      if( var4Characteristic.written() )
      {
        // Read the new value from the characteristic
        unsigned char var4Value = var4Characteristic.value();
        if(var4Value==1)
        {
          followTag=true;
        }
        else
        {
          followTag=false;
        }
      }
      if( var5Characteristic.written() )
      {
        // Read the new value from the characteristic
        unsigned char var5Value = var5Characteristic.value();
        if(var5Value==1)
        {
          cleanWater=true;
        }
        else
        {
          cleanWater=false;
        }
      }      


      // Έλεγχος για χειρονομίες
      if(enableGestures)
      {
        // Check if any faces are detected
        if( gfd.getFaceNumber() > 0 )
        {
          // Retrieve face score and location
          uint16_t faceScore = gfd.getFaceScore();
          uint16_t faceX = gfd.getFaceLocationX();
          uint16_t faceY = gfd.getFaceLocationY();

          // Print the face detection results
          sprintf(str, "detect face at (x = %d, y = %d, score = %d)\n", faceX, faceY, faceScore);
          Serial.print(str);

          // Print the gesture detection results
          // - 1: LIKE (👍) - blue
          // - 2: OK (👌) - green
          // - 3: STOP (🤚) - red
          // - 4: YES (✌) - yellow
          // - 5: SIX (🤙) - purple
          uint16_t gestureType = gfd.getGestureType();
          uint16_t gestureScore = gfd.getGestureScore();

          // Print the gesture detection results
          sprintf(str, "detect gesture %d, score = %d\n", gestureType, gestureScore);
          Serial.print(str);
          if( gestureType==1 )        // 👍: μπροστά
          {
            if(leftSpeed!=4)
            {
              UpdateSpeedMotor1(4);
              var1Characteristic.writeValue(4);
            }
            if(rightSpeed!=4)
            {
              UpdateSpeedMotor2(4);
              var2Characteristic.writeValue(4);
            }
            matrix.loadFrame(forward); // εμφάνισε εικονίδιο βέλος μπροστά
          }
          else if( gestureType==3 )   // 🤚: stop
          {
            if(leftSpeed!=0)
            {
              UpdateSpeedMotor1(0);
              var1Characteristic.writeValue(0);
            }
            if(rightSpeed!=0)
            {
              UpdateSpeedMotor2(0);
              var2Characteristic.writeValue(0);
            }
            matrix.loadFrame(stop); // εμφάνισε εικονίδιο stop

          }
          else if( gestureType==5 )     // 🤙: πίσω
          {
            if(leftSpeed!=-4)
            {
              UpdateSpeedMotor1(-4);
              var1Characteristic.writeValue(-4);
            }
            if(rightSpeed!=-4)
            {
              UpdateSpeedMotor2(-4);
              var2Characteristic.writeValue(-4);
            }
            matrix.loadFrame(backward); // εμφάνισε εικονίδιο βέλος πίσω
          } 
        }
      }
      else
      {
        matrix.loadFrame(happy); // εμφάνισε εικονίδιο happy
      }

      // Έλεγχος για εντολή παρακολούθησης πινακίδας
      if( followTag )
      {
        if( !found )  // αν δεν έχει βρεθεί η πινακίδα
        {
            // τότε το σκάφος σταματά
            if(leftSpeed!=0)
            {
              UpdateSpeedMotor1(0);
              var1Characteristic.writeValue(0);
            }
            if(rightSpeed!=0)
            {
              UpdateSpeedMotor2(0);
              var2Characteristic.writeValue(0);
            }
          // η κάμερα ξεκινά από τέρμα αριστερά και σαρώνει το χώρο μέχρι τέρμα δεξιά,
          // μέχρι να εντοπίσει την πινακίδα
          pos=180;
          while( pos>0 && !found )
          {
            myservo.write(pos);
            delay(15);
            if (huskylens.requestBlocks(ID1))
            {
              if ( huskylens.count(ID1)>0 )   // αν βρέθηκε μια πινακίδα
              {
                found=true;
              }
              else
              {
                pos--;
              }
            }
          }
        }
        if( found )     // αν εντοπίστηκε η πινακίδα, τότε 
        {
          // μέχρι να κεντραριστεί η κάμερα,
          // θα παρακολουθεί συνεχώς την πινακίδα με τη βοήθεια του servo
          //request blocks tagged ID == ID1 from HUSKYLENS
          if (huskylens.requestBlocks(ID1))
          {
            if ( huskylens.count(ID1)>0 )   // αν βρέθηκε μια πινακίδα
            {
              HUSKYLENSResult result = huskylens.get(ID1, 0);
              int x = result.xCenter;
  
              // αντί για τη μέση τιμή (160) χρησιμοποιούμε τις τιμές 135
              // και 185, για να δώσουμε μια ανοχή και να αποφύγουμε τις
              // συνεχείς κινήσεις του servo μοτέρ
              if( x<135 )
              {
                // το servo κινείται προς τα αριστερά (μέχρι 180 μοίρες)
                if( pos<180 ) pos++;
                else pos=180;
              }
              else if( x>185 )
              {
                // το servo κινείται προς τα δεξιά (μέχρι 0 μοίρες)
                if( pos>0 ) pos--;
                else pos=0;
              }
              myservo.write(pos);
              delay(15);
            }
          }

          // αφού η κάμερα έστριψε προς την πινακίδα, κατόπιν θα αρχίσει να στρίβει όλο το σκάφος
          if( pos>100 )  // δηλ. αν η κάμερα έστριψε προς τα αριστερά
          {
            // τότε και το σκάφος στρίβει προς τα αριστερά
            if(leftSpeed!=-3) 
            {
              UpdateSpeedMotor1(-3);
              var1Characteristic.writeValue(-3);
            }
            if(rightSpeed!=3)
            {
              UpdateSpeedMotor2(3);
              var2Characteristic.writeValue(3);
            }
          }
          else if( pos<80 )  // αλλιώς αν η κάμερα έστριψε προς τα δεξιά
          {
            // τότε και το σκάφος στρίβει προς τα δεξιά
            if(leftSpeed!=3)
            {
              UpdateSpeedMotor1(3);
              var1Characteristic.writeValue(3);
            }
            if(rightSpeed!=-3)
            {
              UpdateSpeedMotor2(-3);
              var2Characteristic.writeValue(-3);
            }
          }
          else   // αλλιώς, δηλ. αν η κάμερα κεντραρίστηκε
          {
            // τότε το σκάφος σταματά
            if(leftSpeed!=0)
            {
              UpdateSpeedMotor1(0);
              var1Characteristic.writeValue(0);
            }
            if(rightSpeed!=0)
            {
              UpdateSpeedMotor2(0);
              var2Characteristic.writeValue(0);
            }
          }
        }
        else    // αν δεν εντοπίστηκε η πινακίδα, τότε στρίψε λίγο το σκάφος για να ξανασαρώσει παραπέρα
        {
          // το σκάφος στρίβει για λίγο (2 sec) προς τα δεξιά
          UpdateSpeedMotor1(1);
          var1Characteristic.writeValue(1);
          UpdateSpeedMotor2(-1);
          var2Characteristic.writeValue(-1);
          delay(2000);
          UpdateSpeedMotor1(0);
          var1Characteristic.writeValue(0);
          UpdateSpeedMotor2(0);
          var2Characteristic.writeValue(0);
        }
      }
      else  // δηλ. αν δεν είναι τσεκαρισμένο το followTag
      {
        found=false;
      }

      // Έλεγχος για εντολή καθαρισμού του νερού
      if(cleanWater && !cleaning)
      {
        // Αρχικά ξετυλίγουμε την τροχαλία
        digitalWrite(dirPin, HIGH);
        strofes=0;      // μετράμε τις στροφές που θα κάνει η τροχαλία μέχρι το βυθό
        distance=getUnderWaterDistance();
        // ξετυλίγουμε μέχρι 10cm από το βυθό, αγνοώντας όταν είναι έξω από το νερό (distance=0), και το πολύ έως 4 πλήρεις περιστροφές του stepper
        while( (distance>100 || distance==0) && strofes<=800 )
        {
          digitalWrite(stepPin, HIGH);
          delayMicroseconds(3000);
          digitalWrite(stepPin, LOW);
          delayMicroseconds(3000);
          strofes++;
          if( strofes%40 == 0 )     // κάθε 40 βήματα του stepper, ξαναμετράμε το βάθος
            distance=getUnderWaterDistance();
        }
        cleaning=true;
      }
      // Έλεγχος για εντολή τερματισμού του καθαρισμού νερού
      if(!cleanWater && cleaning)
      {
        // Τυλίγουμε την τροχαλία
        digitalWrite(dirPin, LOW);
        // περιστρέφουμε το stepper ανάποδα, για όσες στροφές ξετυλίχτηκε προηγουμένως
        for (int x = 0; x < strofes; x++)
        {
          digitalWrite(stepPin, HIGH);
          delayMicroseconds(3000);
          digitalWrite(stepPin, LOW);
          delayMicroseconds(3000);
        }
        strofes=0;
        cleaning=false;        
      }
    }

    // Handle disconnection
    Serial.print("Disconnected from: ");
    Serial.println(central.address());
  }
}

// Αριστερός κινητήρας
void UpdateSpeedMotor1(int newSpeed)
{
  if( leftSpeed == newSpeed )
    return;

  int arxiki;
  int teliki;
  if(leftSpeed==0) arxiki=0;
  else arxiki = 180 + (abs(leftSpeed)-1)*25;  // κάθε βαθμίδα της κλίμακας ταχύτητας ανεβαίνει 25 κατά PWM,
  if(newSpeed==0) teliki=0;
  else teliki = 180 + (abs(newSpeed)-1)*25;   // δηλαδή 1->180, 2->205, 3->230, 4->255
  
  if( leftSpeed >= 0 && newSpeed >= 0 )  // μπροστά
  {
    digitalWrite(in1, HIGH);
    digitalWrite(in2, LOW);
    if( teliki > arxiki )    // σταδιακή αύξηση ταχύτητας
    {
      GradualIncreaseSpeed(enA, arxiki, teliki);
    }
    else      // μείωση κατευθείαν
    {
      analogWrite(enA, teliki);
    }
  }
  else if( leftSpeed <= 0 && newSpeed <= 0 )   // πίσω
  {
    digitalWrite(in1, LOW);
    digitalWrite(in2, HIGH);
    if( teliki > arxiki )    // σταδιακή αύξηση ταχύτητας
    {
      GradualIncreaseSpeed(enA, arxiki, teliki);      
    }
    else      // μείωση κατευθείαν
    {
      analogWrite(enA, teliki);
    }
  }
  else if( leftSpeed > 0 && newSpeed < 0 )   // αλλαγή από μπροστά πίσω
  {
    // αρχικά μηδενισμός ταχύτητας
    analogWrite(enA, 0);

    digitalWrite(in1, LOW);
    digitalWrite(in2, HIGH);
    GradualIncreaseSpeed(enA, 0, teliki);
  }
  else if( leftSpeed < 0 && newSpeed > 0 )   // αλλαγή από πίσω μπροστά
  {
    // αρχικά μηδενισμός ταχύτητας
    analogWrite(enA, 0);

    digitalWrite(in1, HIGH);
    digitalWrite(in2, LOW);
    GradualIncreaseSpeed(enA, 0, teliki);
  }  
  leftSpeed = newSpeed;
}

// Δεξιός κινητήρας
void UpdateSpeedMotor2(int newSpeed)
{
  if( rightSpeed == newSpeed )
    return;

  int arxiki;
  int teliki;
  if(rightSpeed==0) arxiki=0;
  else arxiki = 180 + (abs(rightSpeed)-1)*25;  // κάθε βαθμίδα της κλίμακας ταχύτητας ανεβαίνει 25 κατά PWM,
  if(newSpeed==0) teliki=0;
  else teliki = 180 + (abs(newSpeed)-1)*25;   // δηλαδή 1->180, 2->205, 3->230, 4->255
  
  if( rightSpeed >= 0 && newSpeed >= 0)  // μπροστά
  {
    digitalWrite(in3, HIGH);
    digitalWrite(in4, LOW);
    if( teliki > arxiki )    // σταδιακή αύξηση ταχύτητας
    {
      GradualIncreaseSpeed(enB, arxiki, teliki);
    }
    else      // μείωση κατευθείαν
    {
      analogWrite(enB, teliki);
    }
  }
  else if( rightSpeed <= 0 && newSpeed <= 0 )   // πίσω
  {
    digitalWrite(in3, LOW);
    digitalWrite(in4, HIGH);
    if( teliki > arxiki )    // σταδιακή αύξηση ταχύτητας
    {
      GradualIncreaseSpeed(enB, arxiki, teliki);      
    }
    else      // μείωση κατευθείαν
    {
      analogWrite(enB, teliki);
    }
  }
  else if( rightSpeed > 0 && newSpeed < 0 )   // αλλαγή από μπροστά πίσω
  {
    // αρχικά μηδενισμός ταχύτητας
    analogWrite(enB, 0);

    digitalWrite(in3, LOW);
    digitalWrite(in4, HIGH);
    GradualIncreaseSpeed(enB, 0, teliki);
  }
  else if( rightSpeed < 0 && newSpeed > 0 )   // αλλαγή από πίσω μπροστά
  {
    // αρχικά μηδενισμός ταχύτητας
    analogWrite(enB, 0);

    digitalWrite(in3, HIGH);
    digitalWrite(in4, LOW);
    GradualIncreaseSpeed(enB, 0, teliki);
  }  
  rightSpeed = newSpeed;
}

// Για σταδιακή μεταβολή της ταχύτητας
void GradualIncreaseSpeed(int motorEnablePin, int arxiki, int teliki)
{
  for( int i = arxiki; i <= teliki; i+=5 )
  {
    analogWrite(motorEnablePin, i);
    //Serial.println(i);
    delay(10);
  }
}
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
